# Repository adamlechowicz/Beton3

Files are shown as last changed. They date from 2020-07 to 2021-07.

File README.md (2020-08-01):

# Béton3
**A programmable, QMK-compatible, 3 key macro pad with an OLED screen and concrete knob rotary encoder.**

Definition of béton brut
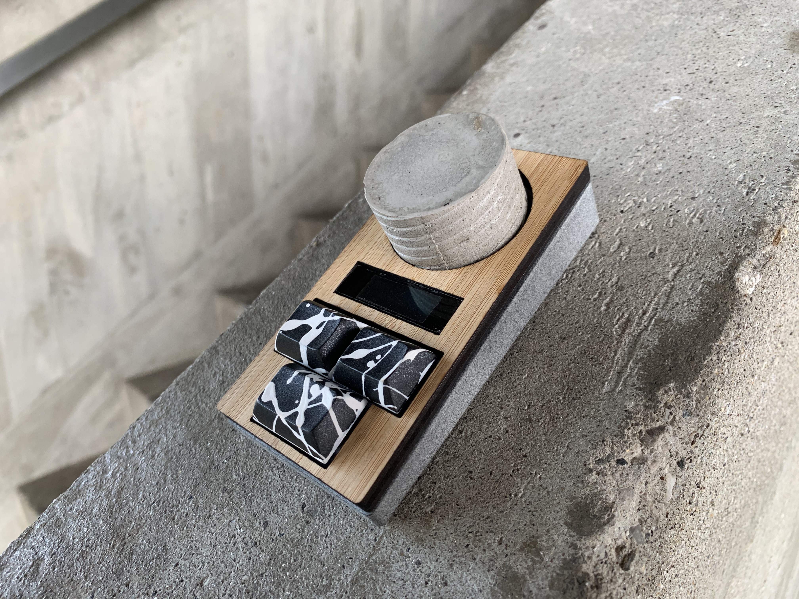
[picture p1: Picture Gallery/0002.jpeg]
Picture of Béton3


Béton3 is an open-source macropad design based around the QMK-compatible Pro Micro platform, MX-mount keyswitches and a commonly available, clickable rotary encoder design.

The defining feature of Béton3 is the cast concrete rotary encoder knob, created using a 3D printed mold that results in a distinct, weighty knob with luxurious inertia and precise steps, much like a premium stereo system.  Using the Béton3 stock firmware, the smooth rotary encoder performs three volume control functions: volume up, volume down, and mute/unmute.

Below the rotary encoder, the 0.91" OLED screen is a bright, programmable canvas for information, text or animations.  Using the Béton3 stock firmware, fluid animations quickly respond to button and knob inputs with icons representing media control and volume control actions.

Finally, three Cherry MX-compatible switches provide a basis for programmable macros, supporting large, 1.25u and 1.5u keycaps for easy muscle memory access.  Using the Béton3 stock firmware, three switches perform five media control functions: play/pause, forward, back, fast-forward, and rewind.

To build your own, consult the [Build Guide.](https://github.com/adamlechowicz/Beton3/tree/master/Build%20Guide)

<a href="https://www.buymeacoffee.com/adamlechowicz" target="_blank">Buy Me A Coffee</a>

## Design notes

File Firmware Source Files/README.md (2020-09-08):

# Béton3 Firmware

This folder holds major versions of the firmware for Béton3.  Firmware is written for Arduino Pro Micro and Pro Micro clones (Arduino Leonardo platform in the Arduino IDE).

I recorded a quick and dirty video of the stock firmware's interface at https://www.youtube.com/watch?v=9jtD4WeTKok

The following open source libraries are dependencies for the firmware:
- [AsyncDelay](https://www.arduinolibraries.info/libraries/async-delay)
- [HID-Project](https://www.arduinolibraries.info/libraries/hid-project)
- [TimerOne](https://www.arduinolibraries.info/libraries/timer-one)
- [U8g2](https://www.arduinolibraries.info/libraries/u8g2)
- [ClickEncoder](https://github.com/0xPIT/encoder)

I've made an attempt to document the majority of the code using comments throughout, but if you are using this as a base for a revision and have clarifying questions shoot me an email at alechowicz@umass.edu.

One thing that may help with code readability as well is the simple wiring diagram hosted in a different folder in this repository, at least in terms of understanding which pins connect to which components.

The stock firmware, without modification, hardcodes a basic media control macro pad, with 3 buttons, a rotary encoder, and animations which correspond to the appropriate button press.
- Button 1: Acts as a play/pause button.  Hold down to open the firmware version screen.
- Button 2: Acts as a media next button.  Hold down to (fast forward only works in Windows).
- Button 3: Acts as a media previous button. Hold down to (rewind only works in Windows).
- Rotary Encoder: Clockwise sends media volume up keystrokes, and counter-clockwise sends media volume down keystrokes.  Click acts as a mute keystroke.  Holding the click opens the "about" screen.

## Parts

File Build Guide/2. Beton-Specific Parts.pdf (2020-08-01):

# Béton3 // Build Guide

# Béton3-Specific Parts

Welcome to the second Build Guide for Béton3. This Build Guide outlines the custom

designed parts you’ll need to build Béton3, along with links to 3D and physical files for each,

and some raw materials you’ll need for final assembly.

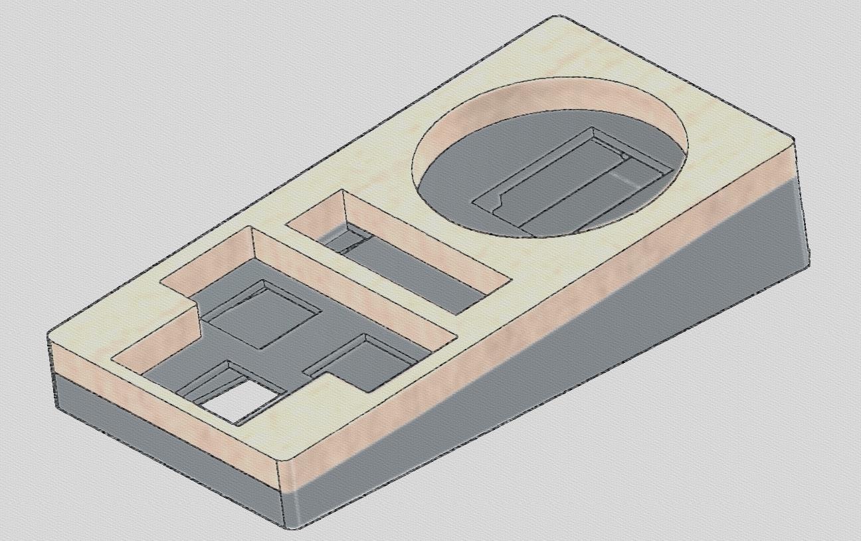
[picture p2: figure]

## Table of Contents

- Pg. 2 – Main Chassis (3D Printed)
- Pg. 3 – Bottom Cover (3D Printed)
- Pg. 4 – Top Bezel (Laser-cut)
- Pg. 5 – Concrete Knob Mold (3D Printed, 3 pieces)
- Pg. 6 – Raw Materials

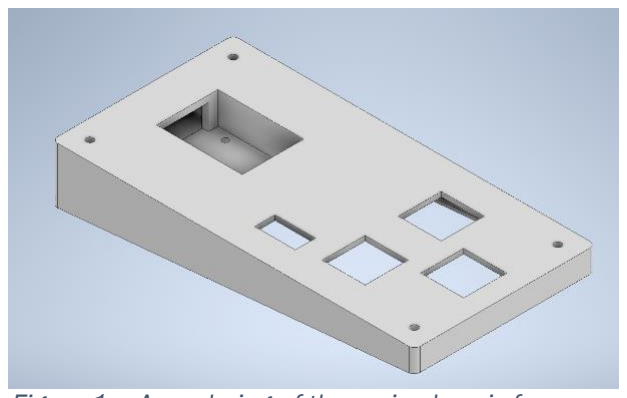
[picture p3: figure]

## Main Chassis (3D Printed)

Béton3’s main chassis is a 3D-printed part. For

best results, I would recommend using a printing

service with a high-resolution printer. I have had

great success with the Multijet Fusion 3D printing

process, available on many sites such as

Shapeways (https://www.shapeways.com/) and Sculpteo. (https://www.sculpteo.com/en/) Notably, for my

rendition of Béton3, I used Multijet Fusion (Not

Dyed, Grey) plastic, which is generally the cheapest option on these printing sites and results

in a unique rough finish that hides layers and blends with the “concrete” aesthetic

reinforced by the encoder knob.

Printing

3D files for the main chassis are available on the Beton3 GitHub repository, with the

filenames betonbase.ipt and betonbase.stl. If you are just printing, you’ll want to download

the STL file as it is compatible with most 3D printing sites (Units are in millimeters).

(Link to files) (https://github.com/adamlechowicz/Beton3/tree/master/Physical%20Files%20(3D%20printing%20and%20laser%20cutting)/3D-printed%20Case)

Figure 1 – A rendering of the main chassis for Béton3

## Bottom Cover (3D Printed)

Béton3’s sliding bottom cover is also a 3D printed

part, which slides along rails shaped into the

main chassis. For best results, I would

recommend using a printing service with a high-

resolution printer. I have had great success with

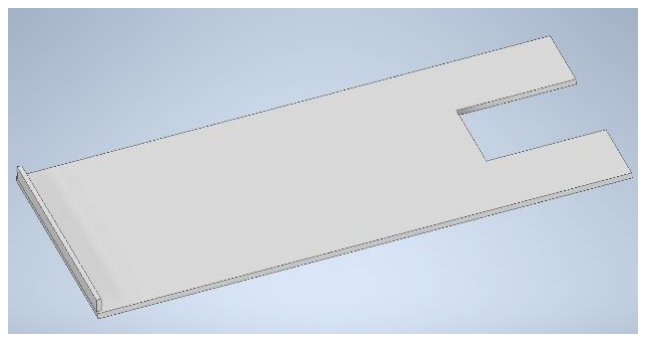
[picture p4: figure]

the Multijet Fusion 3D printing process, available on many sites such as Shapeways (https://www.shapeways.com/) and

Sculpteo. (https://www.sculpteo.com/en/) Notably, for my rendition of Béton3, I used Multijet Fusion (Not Dyed, Grey)

plastic, which is generally the cheapest option on these printing sites and results in a unique

rough finish that hides layers and blends with the “concrete” aesthetic reinforced by the

encoder knob.

You may notice that the bottom cover is not fully rectangular – this is a result of clearance

issues with the frontmost switch. The small cutout allows for plenty of space to solder wires

to that front switch – and don’t worry, it isn’t just left open like that. The gap will be covered

later with a piece of foam, and is completely invisible once assembled.

If you feel strongly about this gap, you could solve this clearance issue by essentially making

the main chassis taller to allow more room – I decided the extra height wasn’t worth it for my

own means.

Printing

3D files for the sliding cover are available on the Beton3 GitHub repository, with the

filenames betonbottom.ipt and betonbottom.stl. If you are just printing, you’ll want to

download the STL file as it is compatible with most 3D printing sites (Units are in

millimeters).

(Link to files) (https://github.com/adamlechowicz/Beton3/tree/master/Physical%20Files%20(3D%20printing%20and%20laser%20cutting)/3D-printed%20Case)

Figure 2 – A rendering of the sliding bottom cover

## Top Bezel (Laser-cut)

Next to the concrete encoder knob,

Béton3’s laser-cut top bezel constitutes

the most distinctive aspect of the design.

The symmetrical layout of the top bezel is

encoded in an Adobe Illustrator file that

can be used with online laser-cutting

services such as Ponoko. (https://www.ponoko.com/)

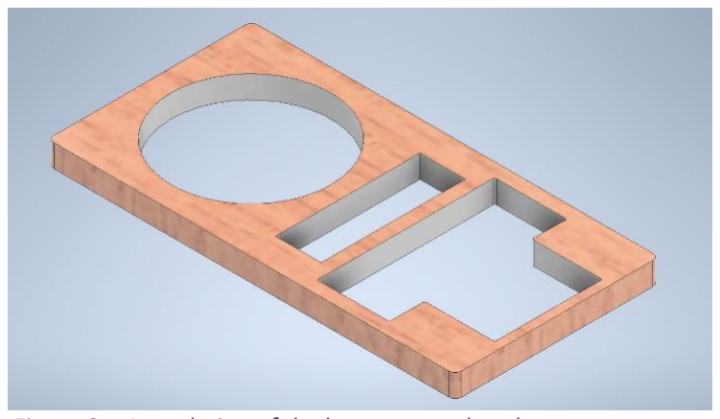
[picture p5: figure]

If you haven’t used an online laser-cutting service, it works much the same way as an online

3D printing service and should be fairly self-explanatory.

Laser Cutting Options

Because the Adobe Illustrator file for this aspect of Béton3 is essentially a 2D file, the top

bezel offers a lot of opportunity for variation and personalization.

For a standard design I would recommend anywhere between 0.24” and 0.26” thickness for

the bezel.

Using Ponoko as an example, there is a wide variety of potential materials to use. You could

use anything from the most basic particleboard to solid walnut hardwood (the price will

reflect your choice, of course). There are also acrylic options, but they may crack using wood

screws, so you might have to devise a different “attachment method”, so to speak. For my

rendition of Béton3, I used Ponoko’s 0.26” thick “Amber Bamboo Plywood” option, which

turned out great. Experiment!

(Link to file) (https://github.com/adamlechowicz/Beton3/tree/master/Physical%20Files%20(3D%20printing%20and%20laser%20cutting)/Laser-cut%20Top%20Bezel)

Figure 3 – A rendering of the laser-cut top bezel.

## Concrete Knob Mold (3D-printed, 3 pieces)

Béton3’s signature feature is a cast,

concrete knob for the rotary encoder.

In order to create the knob, I designed

a specific mold that is 3D printable and

splits into 3 pieces for easy casting,

and features a spiral pattern along the

wall of the knob for grip.

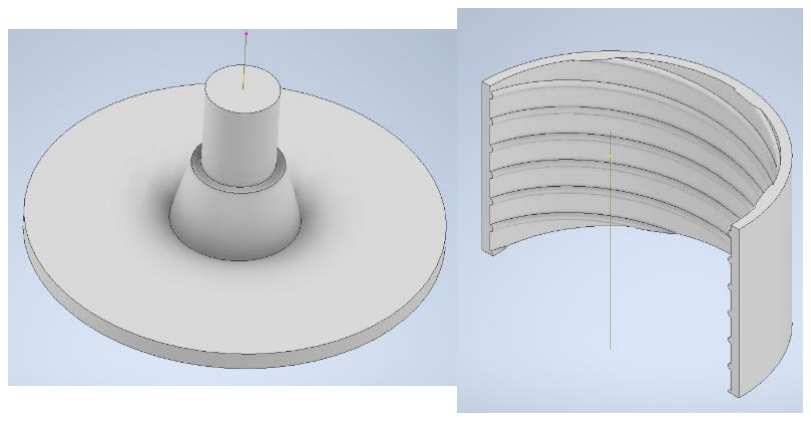
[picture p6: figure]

Like all other 3D printed parts, I would recommend

using a printing service with a high-resolution printer. I have had great success with the

Multijet Fusion 3D printing process, available on many sites such as Shapeways (https://www.shapeways.com/) and

Sculpteo. (https://www.sculpteo.com/en/) For my mold, I used Multijet Fusion (Not Dyed, Grey) plastic, which is generally the

cheapest option on these printing sites.

The actual process of casting the knob is detailed later in the Build Guide, but essentially

two mold sides combine with a mold base to create the full mold.

Printing

3D files for the mold are available on the Beton3 GitHub repository, with the filenames

moldside.ipt, moldside.stl, moldbase.ipt, and moldbase.stl. If you are just printing, you’ll

want to download the STL files as they are compatible with most 3D printing sites (Units are

in millimeters).

You’ll need to print two of the moldside file, and one of the moldbase file.

(Link to files) (https://github.com/adamlechowicz/Beton3/tree/master/Physical%20Files%20(3D%20printing%20and%20laser%20cutting)/3D-printed%20Case)

Figure 4 - The side and base of the concrete mold

## Raw Materials

Finally, you’ll need some basic raw materials to be used for final assembly. These are

commodity items and brand/source isn’t super important, but I have linked some examples

from Amazon that I used/found useful. You may already have some of these materials. Be

sure to check out the later build guides for more information on how I chose all of these, in

case you want to make adjustments:

- Regular Wire – (Amazon) (https://www.amazon.com/gp/product/B07CZT26DM/ref=ppx_yo_dt_b_asin_title_o01_s00?ie=UTF8&psc=1)
- Dupont Wires (with connectors) – (Amazon) (https://www.amazon.com/gp/product/B072L1XMJR/ref=ppx_yo_dt_b_asin_title_o02_s00?ie=UTF8&psc=1)
- Soldering Iron (with solder) – (Amazon) (https://www.amazon.com/gp/product/B07S61WT16/ref=ppx_yo_dt_b_asin_title_o03_s00?ie=UTF8&psc=1)
- Black Matte Plasti Dip (black spray paint should also work) – (Amazon) (https://www.amazon.com/gp/product/B0006SU3QW/ref=ppx_yo_dt_b_asin_title_o04_s00?ie=UTF8&psc=1)
- Electrical Tape, Masking Tape
- 1/16” thick Polycarbonate Sheet – (Amazon) (https://www.amazon.com/gp/product/B07MQTDF4R/ref=ppx_yo_dt_b_asin_title_o06_s00?ie=UTF8&psc=1)
- #2 Wood Screws – ¼” long (you’ll need at least 4)
- Cement (any kind should work, Rockite is a safe and cheap choice) – (Amazon) (https://www.amazon.com/gp/product/B000SDXGUU/ref=ppx_yo_dt_b_asin_title_o07_s00?ie=UTF8&psc=1)
- Hot Glue Gun with Glue Sticks (any temp should work, high temp preferred)
- Sand (any should work as long as doesn’t have too many large rocks or pieces)
- 1/16” thick Neoprene Foam (preferably with adhesive preapplied) – (Amazon) (https://www.amazon.com/6x6-Inch-Neoprene-Plumbing-Material-Protection/dp/B018H9CCPG)

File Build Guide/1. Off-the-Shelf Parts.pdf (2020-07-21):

# Béton3 // Build Guide

# Off-the-Shelf Parts

Welcome to the first Build Guide for Béton3. This Build Guide outlines the “off-the shelf”

parts you’ll need to build Béton3, along with links to purchase compatible parts.


## Table of Contents

- Pg. 2 – Arduino Pro Micro / Pro Micro Clone
- Pg. 3 – Rotary Encoder
- Pg. 4 – 0.91” 128x32 OLED Display
- Pg. 5 – Cherry MX-mount compatible switches
- Pg. 6 – Keycaps

## Arduino Pro Micro / Pro Micro Clone

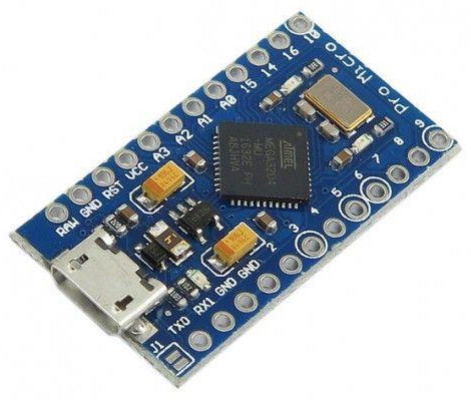
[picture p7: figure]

Béton3 is based on the Arduino Pro Micro platform, a

commonly used platform based on the ATmega32U4

microcontroller. The Pro Micro brings a lot to the table – it’s

affordable, has a vibrant community, and is compatible with

QMK Firmware, (https://docs.qmk.fm/#/) a popular open source firmware for input

devices such as keyboards, mice, and MIDI devices.

Buying Options

One of the best features of the Pro Micro is the sheer spectrum of options available for every

budget.

The most basic option is a Pro Micro clone, the option that I personally chose for my build.

Pro Micro clones are widely available, and generally go for anywhere from $3-10, depending

on shipping speed: (AliExpress) (https://www.aliexpress.com/af/pro-micro.html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) (Amazon) (https://www.amazon.com/s?k=pro+micro&ref=nb_sb_noss_2)

Another option is the SparkFun Pro Micro, the original board design that has since been

cloned endlessly. Theoretically, the SparkFun should perform identically, as it is pin-

compatible with all clones: (SparkFun) (https://www.sparkfun.com/products/12640)

Both above options use micro-USB connectors which have a reputation for breaking off with

lots of insertion cycles. As an alternative, there are some community-made Pro Micro

boards that feature USB-C connectors instead. These boards are more expensive and

higher quality boards that are generally pin-compatible with Pro Micro/clones: (Elite-C V4) (https://keeb.io/products/elite-c-low-profile-version-usb-c-pro-micro-replacement-atmega32u4)

(SparkFun Qwicc) (https://www.sparkfun.com/products/15795)

Figure 1 - A generic Pro Micro clone that you can find everywhere online.

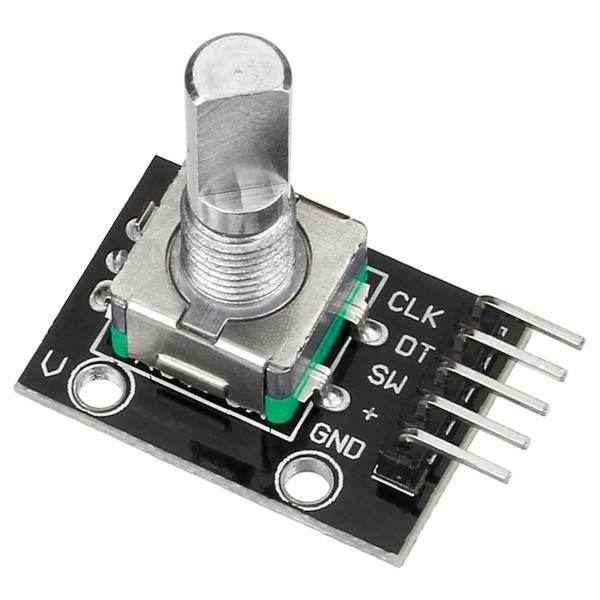
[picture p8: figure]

## Rotary Encoder

Béton3’s chassis is designed around a commonly

available stepped rotary encoder marketed for

Arduino projects. The encoder is sometimes

referred to with a “KY-040” model identifier, and is

generally widely available on e-commerce sites.

Minor differences such as PCB color should be

irrelevant, as long as the PCB form factor is the

same size and the encoder has 5 pins.

Buying Options

These encoders can be picked up for as low as $0.47 on AliExpress. If Prime shipping is

more your speed, you can pick up a pack of multiple encoders for about $1 per encoder:

(AliExpress) (https://www.aliexpress.com/af/rotary-encoder-ky%25252d040.html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)

(Amazon) (https://www.amazon.com/s?k=rotary+encoder+ky-040&ref=nb_sb_noss_1)

Figure 2 - An example of the rotary encoder in question.

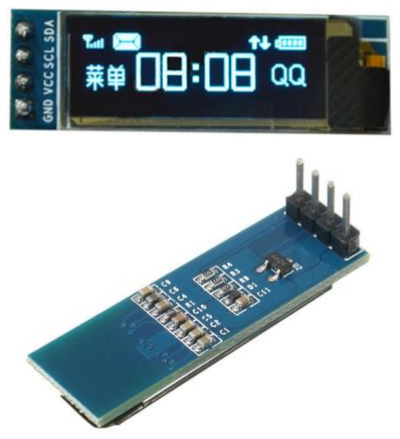
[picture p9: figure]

## 0.91” 128x32 OLED Display

Béton3’s chassis is designed around a particularly

affordable 0.91” OLED screen with 128x32 pixels

that has been used in a few keyboards, most notably

the Satisfaction 75. (https://cannonkeys.com/collections/satisfaction-75)

Like the other parts on this list, this display is

generally widely available on e-commerce sites.

Minor differences such as PCB color are irrelevant,

but watch out for cheaper SKUs of the display on

AliExpress which do not include the PCB.

Buying Options

There are two primary variants of this display, a monochrome blue variant, and a

monochrome white variant. I chose the monochrome white display, but this distinction is up

to personal preference.

These little screens can be picked up for as low as $1.10 on AliExpress. If Prime shipping is

more your speed, you can pick up a screen on Amazon for about $7-8; less if you buy

multiple in a pack.

(AliExpress) (https://www.aliexpress.com/af/128x32-oled.html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)

(Amazon) (https://www.amazon.com/s?k=128x32+oled&ref=nb_sb_noss_2)

Figure 3 – An example of the 128x32 OLED display with the PCB.

## Cherry MX-mount compatible switches


Béton3’s chassis includes 3 square mounting holes

compatible with Cherry MX switches and MX-

compatible switches (Gateron, Kalih BOX, Zeal,

Outemu, etc.) For my initial build, I used an

assortment of Gateron Linears I had sitting in a

drawer, but you’ll probably use your preferred switch.

Switches can cost anywhere from pennies per switch

up to $1 per switch or more for some enthusiast

switches like Zealios or Holy Pandas.

Buying Options

Switches can be found on an endless number of websites all over the internet. There is a

great switch guide (https://www.reddit.com/r/MechanicalKeyboards/wiki/switch_guides) on /r/MechanicalKeyboards that outlines what types of switches are

available and some direction on where to buy them. As usual, some of the more common

switch types manufactured in China are available on AliExpress (https://www.aliexpress.com/af/keyboard-switch.html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) in packs for fairly affordable

prices.

I strongly recommend checking out any one of the multiple mechanical keyboard

communities online for more info about keyswitches.

Figure 4 - The three mounting holes for MX-compatible switches on the Béton3 chassis

## Keycaps

For the three macro keys, Béton3 uses a

somewhat non-standard layout for keycaps.

Keycaps naturally must be MX-compatible cross-

stem keycaps. The layout is comprised of two

upper 1.25u keycaps, and one lower 1.5u keycap.

If you are unfamiliar with keycap sizing in terms of

“u”s, this is an example of a standard keyboard

layout with labeled sizes. (https://support.wasdkeyboards.com/hc/en-us/articles/115009701328-Keycap-Size-Compatibility)


For a standard ANSI keyboard layout, 1.5u is equivalent to the “Tab” key, and 1.25u is

generally equivalent to one of the modifier keys (Ctrl, Alt, Command).

Buying Options

While basic 1u (square-shaped) keycaps are commonplace and can be purchased in small

batches or one-by-one, 1.25u and 1.5u keycaps are a bit more difficult to find.

For a basic option, there is a basic set of 1.25u and 1.5u DSA PBT keycaps available on

AliExpress (https://www.aliexpress.com/af/1.5u-keycap.html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) for about $7.

For something more interesting, you may be able to find “artisan” keycaps on sites such as

Etsy or eBay in the 1.25u and 1.5u sizes.

Finally, if you have spare keycaps lying around the house, you may be able to use keycaps

from your existing set such as “Tab”, “Ctrl”, “Alt”, “|\”, etc.

Please note: Although aesthetically awkward, standard 1u keycaps will fit, and are

completely functional despite the gaps.

Figure 5 - Keycap size layout

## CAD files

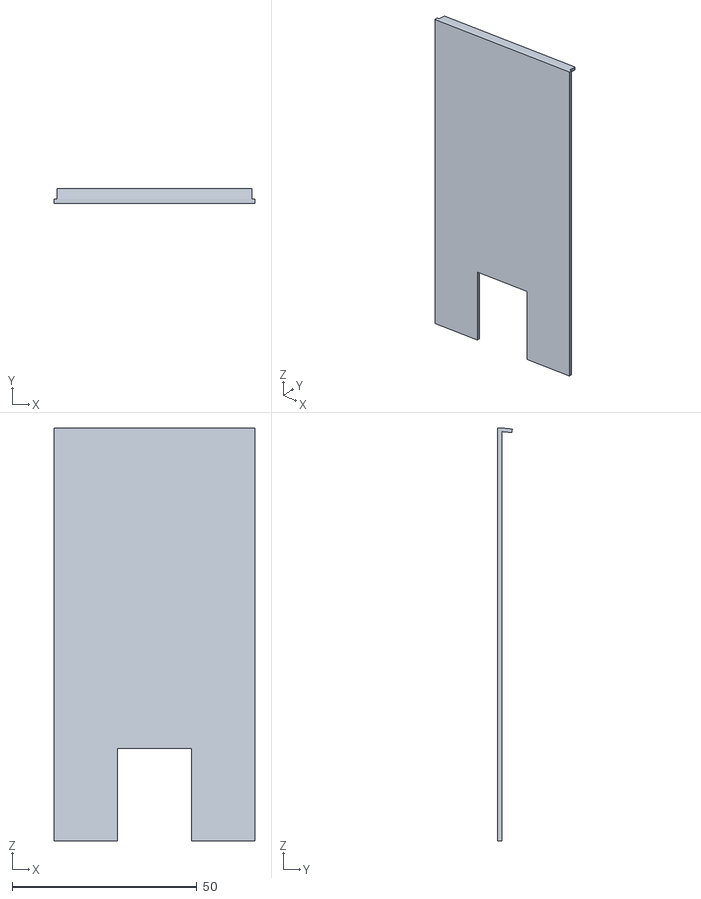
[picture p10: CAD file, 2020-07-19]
Physical Files (3D printing and laser cutting)/3D-printed Case/betonbottom.stl
54.4 x 3.98 x 111.8

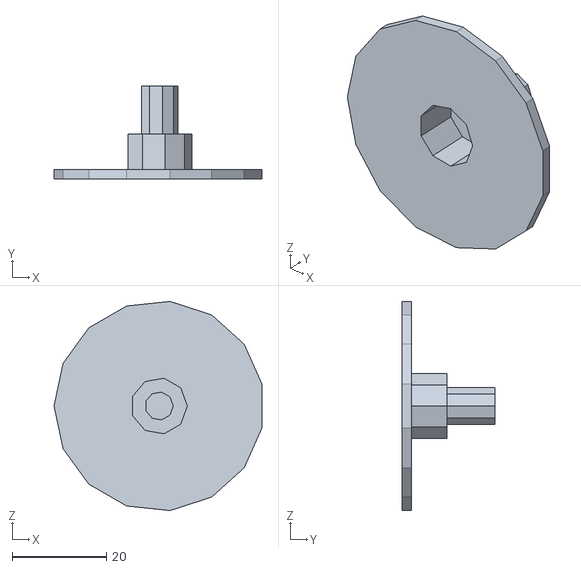
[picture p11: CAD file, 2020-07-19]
Physical Files (3D printing and laser cutting)/3D-printed Concrete Mold/moldbase.stl
44.2 x 19.8 x 44.5

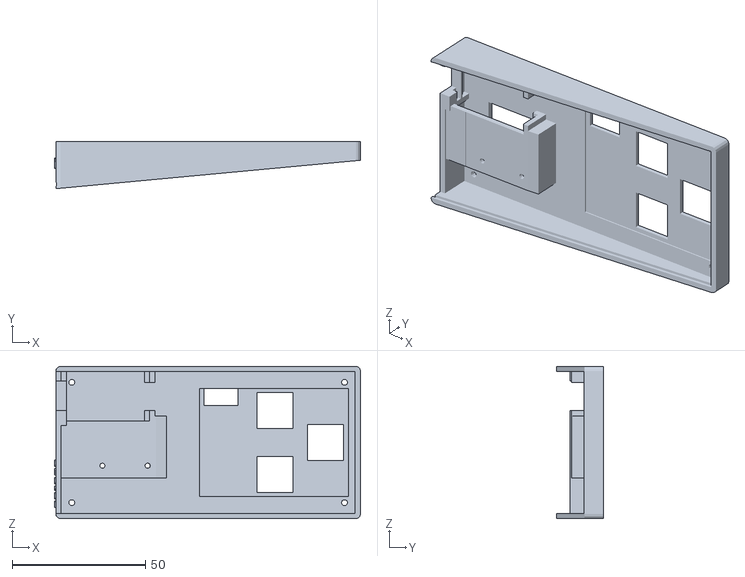
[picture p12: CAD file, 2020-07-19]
Physical Files (3D printing and laser cutting)/3D-printed Case/betonbase.stl
114.8 x 17.8 x 57.2

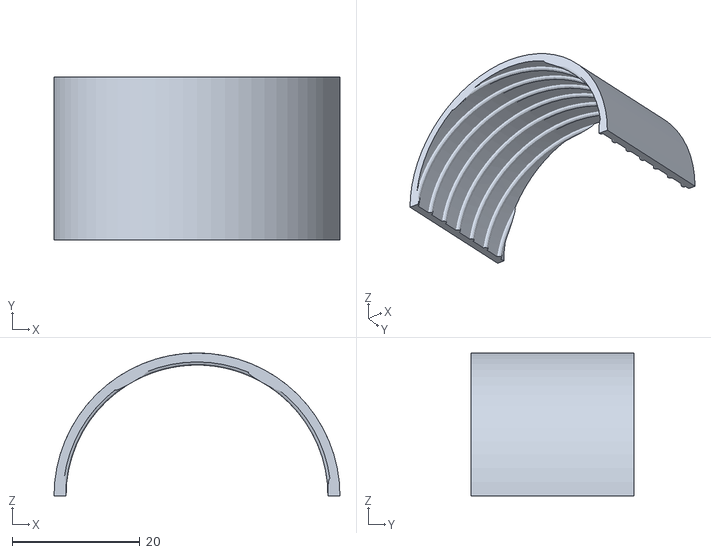
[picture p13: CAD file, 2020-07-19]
Physical Files (3D printing and laser cutting)/3D-printed Concrete Mold/moldside.stl
44.7 x 25.4 x 22.4

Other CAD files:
Physical Files (3D printing and laser cutting)/3D-printed Case/betonbase.ipt
Physical Files (3D printing and laser cutting)/3D-printed Case/betonbottom.ipt
Physical Files (3D printing and laser cutting)/3D-printed Concrete Mold/moldbase.ipt
Physical Files (3D printing and laser cutting)/3D-printed Concrete Mold/moldside.ipt
Physical Files (3D printing and laser cutting)/Full Assembly (Autodesk Inventor)/Assembly Beton (shrinkwrapped).ipt

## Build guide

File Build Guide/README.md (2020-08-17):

# Béton3
# Build Guide

The Build Guide for Béton3 is split up into topics, with PDF files for each topic:

**note:** Links don't seem to work through the GitHub PDF viewer.  Download the PDF files if necessary.

1. **Off-the-Shelf Parts**
2. **Beton-Specific Parts**
3. **Soldering Guide**
4. **Final Assembly Guide**

- Appendix A. **Making a Screen Bezel from Polycarbonate**
- Appendix B. **Casting a Concrete Volume Knob**
- Appendix C. **Flashing Beton3 Stock Firmware**

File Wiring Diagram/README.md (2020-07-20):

# Béton3
# Wiring Diagram

Files:
- **Wiring Diagram.pdf** - A pretty basic PDF outline of the wiring for Béton3.

This wiring diagram is intended as a quick reference guide to the wiring setup I used for Béton3.  This diagram should work verbatim for all Arduino Pro Micros, Pro Micro clones, and Pro Micro pin-compatible boards.  Boards that are a similar form factor but not pin-compatible may require some shuffling around on your end.

- **Rotary Encoder**
  - GND to GND on Pro Micro
  - **+** to RAW (6-12V) on Pro Micro
  - SW to A2 on Pro Micro
  - DT to A1 on Pro Micro
  - CLK to A0 on Pro Micro

- **OLED Display**
  - GND to GND on Pro Micro
  - VCC to VCC on Pro Micro
  - SDA to SDA (pin 2) on Pro Micro
  - SCL/SCK to SCL (pin 3) on Pro Micro
  
- **Switch #1**
  - One pin to GND on Pro Micro
  - Other pin to PIN 7 on Pro Micro
  
- **Switch #2**
  - One pin to GND on Pro Micro
  - Other pin to PIN 8 on Pro Micro

- **Switch #3**
  - One pin to GND on Pro Micro
  - Other pin to PIN 9 on Pro Micro

For more information on wiring up Béton3, consult the [Build Guide.](https://github.com/adamlechowicz/Beton3/tree/master/Build%20Guide)

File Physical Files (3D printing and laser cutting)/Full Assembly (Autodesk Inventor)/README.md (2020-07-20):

# Béton3
# Assembly Example

Files:
- **Assembly Beton (shrinkwrapped).ipt** - An Autodesk Inventor part file that is a simple representation of how Béton3 assembles.  3D files incorporated are included elsewhere in the repository.

For more information on the assembling Béton3 parts, consult the [Build Guide.](https://github.com/adamlechowicz/Beton3/tree/master/Build%20Guide)

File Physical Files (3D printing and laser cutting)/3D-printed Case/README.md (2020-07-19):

# Béton3
# 3D-printed Case

Files:

- betonbase.ipt - Original Autodesk Inventor file
- **betonbase.stl** - The primary structural base for Béton3.  STL File uses millimeters for units.

- betonbottom.ipt - Original Autodesk Inventor file
- **betonbottom.stl** - Bottom sliding cover for Béton3.  STL File uses millimeters for units.

The STL files can be directly uploaded to a 3D-printing service for printing.  In my initial build, I used [Sculpteo](https://www.sculpteo.com/en/) for printing, and chose Multijet Fusion (Not Dyed, Grey) plastic.  Not only is this plastic the cheapest option on many 3D-printing sites, the Multijet Fusion process creates a unique rough finish that hides layers and blends with the "concrete" aesthetic of Béton3, while striking a great balance between elasticity and rigidity.

As I don't personally have one, I have not tried printing these files with a desktop printer such as a MakerBot.  Some part geometry may have to be modified for a satisfactory result on a "traditional" FDM printer.

For more information on the 3D-printed main case, consult the [Build Guide.](https://github.com/adamlechowicz/Beton3/tree/master/Build%20Guide)

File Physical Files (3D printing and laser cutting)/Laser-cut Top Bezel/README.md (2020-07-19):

# Béton3
# Laser-cut Top Bezel

Files:
- **topbezel.ai** - An Adobe Illustrator file to use with a laser cutting service such as [Ponoko](https://www.ponoko.com/), in order to create the top bezel for Béton3.

This file can be directly uploaded to Ponoko for laser-cutting.  For best results, the thickness of the top bezel should be between 0.24 and 0.26 inches.

For the material, anything wood or wood-adjacent (plywood, particleboard) should work, as long as you can use screws to attach the top bezel to the 3D-printed case.  I have not tested other types of materials such as acrylic, although they should theoretically work, assuming you can attach the resulting product to the bottom case.

For more information on the top bezel, consult the [Build Guide.](https://github.com/adamlechowicz/Beton3/tree/master/Build%20Guide)

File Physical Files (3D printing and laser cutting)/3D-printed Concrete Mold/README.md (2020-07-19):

# Béton3
# 3D-printed Concrete Knob Mold

The 3D files in this folder combine to create a concrete mold for Béton3's rotary encoder knob.

Files:

- moldside.ipt - Original Autodesk Inventor file
- **moldside.stl** - 180 degrees of the concrete mold's side.

- moldbase.ipt - Original Autodesk Inventor file
- **moldside.stl** - Concrete mold's base.

In order to create a functioning mold, you'll need to print 2 of the moldside file, and 1 of the moldbase file.

For more information on using the resultant mold, consult the [Build Guide.](https://github.com/adamlechowicz/Beton3/tree/master/Build%20Guide)

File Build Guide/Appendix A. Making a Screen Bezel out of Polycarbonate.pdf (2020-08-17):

# Béton3 // Build Guide

# Appendix A: Making a Screen Bezel from Polycarbonate

Welcome to Appendix A: Making a Screen Bezel from Polycarbonate. This quick guide will

guide you through the process making a polycarbonate screen bezel out of a sheet of

commodity 1/16” inch thick clear polycarbonate.


## Table of Contents

- Pg. 2 – Overview of Materials
- Pg. 3 – Cutting the Polycarbonate to Size
- Pg. 4 – Masking Off the Polycarbonate
- Pg. 5 – Painting the Polycarbonate

## Overview of Materials

In order to create a polycarbonate screen bezel, you’ll need the following materials and

parts:

1. A sheet of clear polycarbonate, 1/16” inch thick.
2. Utility knife
3. Fine-tip marker or sharpie
4. Ruler/Straight Edge
5. Black Plasti Dip or Spray Paint (personal preference)
6. Masking tape or electrical tape
7. Scissors
8. (recommended) Beton3 Wooden Top Bezel (to test fit)
9. Sandpaper (to make minor adjustments if cut too big)

## Cutting the Polycarbonate to Size

First, you’ll want to cut a rectangle out of the polycarbonate sheet.

The size of the screen bezel will be 39.5 mm x 11.5 mm.

I found that the best way to do this is using the “score and snap” method outlined under

“Method 1” on wikiHow: https://www.wikihow.com/Cut-Polycarbonate

Use the ruler to mark off the rectangle you’re trying to cut on the protective white plastic

that’s covering the polycarbonate underneath. Follow the wikiHow guide to score the

polycarbonate, and snap it off, leaving a clean, straight edge.

I would recommend starting with the long side first, wasting less polycarbonate in case you

decide to retry, like so:

If you have a laser-cut top bezel, try test fitting the rectangle into the cutout for the OLED

display to see if it will fit. Use sandpaper to sand off some polycarbonate if it “almost” fits in

the rectangular cutout.

Once you’ve scored and snapped a satisfactory rectangle of polycarbonate, peel off the

white protective plastic on ONE side and proceed to the next step.

39.5 mm

11.5 mm

Polycarbonate Sheet

B
E
Z
E
L

## Masking Off the Polycarbonate

Once you’ve cut out this rectangle, the final step is to paint the excess polycarbonate around

the edges of the OLED display. In order to do this, the first step will be to mask off a

rectangular cutout of the polycarbonate rectangle where the OLED display will shine through.

Use scissors to cut out a rectangle of masking tape or electrical tape and position it as such:

The tape should be

25 mm x 8 mm.

When positioning the tape, be cognizant of the display’s position relative to the rectangular

cutout in the wooden laser-cut bezel. For me, this was roughly centered, but this may be

different for you, especially if you’ve already substantially completed a Beton3.

You’ll want to stick this tape to the side of the polycarbonate rectangle where you have

peeled off the white protective plastic.

The other side of the bezel should still have white protective plastic covering it, to prevent

any paint from getting on that side. If your polycarbonate sheet didn’t come with a white

protective sheet on both sides, take a large piece of masking tape or electrical tape and

mask off the entire other side of the polycarbonate sheet too – this will be critical to the final

look.

Once finished masking, go on to painting!

Polycarbonate

Rectangle

Masking Tape or Electrical Tape

25 mm

8 mm

## Painting the Polycarbonate

Once you’ve masked everything off, set the polycarbonate down somewhere where you can

use spray paint, with the 25 x 8 mm cut rectangle of tape facing UP. Now, using either your

black Plasti Dip or black spray paint, spray the polycarbonate from all four sides, at about a

45º angle from the ground. This will evenly coat both the back of the bezel, and the sides,

hiding any imperfections in the scored sides of the bezel.

Don’t use too much – you want to be able to peel off that tape, and one good coat is more

than sufficient.

Leave the bezel somewhere to dry for a little bit.

After roughly 30-45 minutes (depending on the paint you used), go back and peel off the

masking or electrical tape that you used earlier. Doing this step before the pain cures

completely gives a cleaner line. If you are having trouble getting the tape free of the rest of

the paint, you can lightly try using a razor blade or an X-Acto knife to cut around the edge of

the tape and peel it away.

Once all the masking tape is gone, you have successfully made a polycarbonate OLED

screen bezel out of a sheet of polycarbonate!

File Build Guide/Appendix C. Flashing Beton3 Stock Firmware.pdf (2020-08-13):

# Béton3 // Build Guide

# Appendix C: Flashing Beton3 Stock Firmware

Welcome to Appendix C: Flashing Beton3 Stock Firmware. This quick guide will guide you

through the process of flashing a Pro Micro/Pro Micro compatible board with the Beton3

Stock Firmware, which is recommended to be completed after final assembly is complete.


## Table of Contents

- Pg. 2 – What You Will Need
- Pg. 3 – Setting Up Environment (Arduino IDE and required libraries)
- Pg. 4 – Downloading and Opening Stock Firmware
- Pg. 5 – Final Steps, Flashing and Testing

## What You Will Need

Before flashing the stock firmware, you’ll need access to the following:

1. A computer that can run Arduino IDE (Windows, Mac and Linux are a safe bet)
2. A compatible USB Cable that can connect from your Pro Micro to said computer

(probably microUSB or USB-C)

3. An assembled Beton3 (note: you can theoretically flash the Pro Micro by itself, but

testing is pretty much impossible without components connected)

4. Internet connection

## Setting Up Environment (Arduino IDE and required libraries)

Step 1. Install Arduino IDE:
- Download and Install (https://www.arduino.cc/en/main/software)
- Use the guide (https://www.arduino.cc/en/Guide) if necessary
Step 2. Download Required Libraries (.zip files, get the latest version):
- AsyncDelay (https://www.arduinolibraries.info/libraries/async-delay)
- HID-Project (https://www.arduinolibraries.info/libraries/hid-project)
- TimerOne (https://www.arduinolibraries.info/libraries/timer-one)
- U8g2 (https://www.arduinolibraries.info/libraries/u8g2)
- ClickEncoder (https://github.com/0xPIT/encoder)

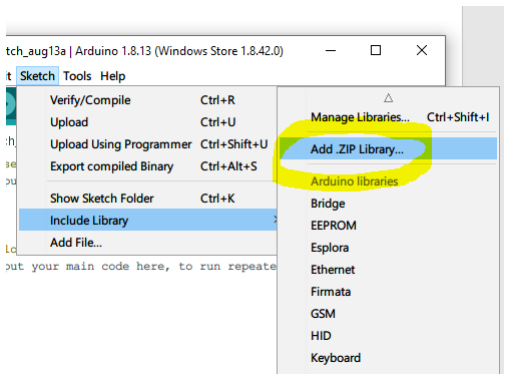
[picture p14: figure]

Step 3. Install Required Libraries
- In Arduino IDE, go to Sketch > Include

Library > Add .ZIP Library… and click

- Choose one of the five .zip files you

downloaded in Step 2 and click “Open”

- Repeat for the other four .zip files you

downloaded in Step 2

Step 4. Configure Arduino Mode
- In Arduino IDE, go to Tools > Board: “…” > and click “Arduino Leonardo”.

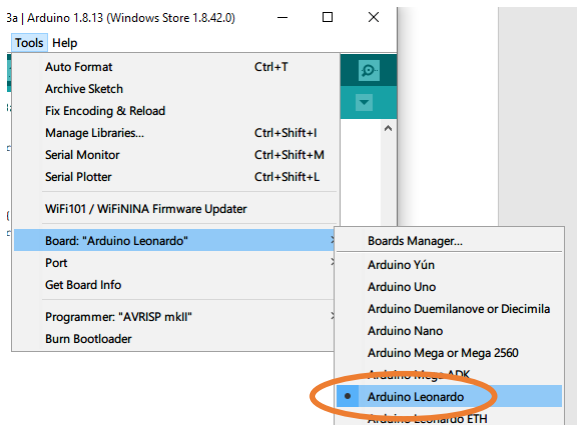
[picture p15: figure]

## Downloading and Opening Stock Firmware

Step 1. Cloning the Repository
- If you haven’t already, clone the entire repository (https://github.com/adamlechowicz/Beton3) to your computer. If you’re familiar

with Git, do this step however you see fit, but if you aren’t, continue…

- On GitHub, hover over “Code” and click

“Download ZIP”.

- Save the repository somewhere

convenient

Step 2. Opening the Firmware in Arduino IDE
- Navigate to the repository folder and into

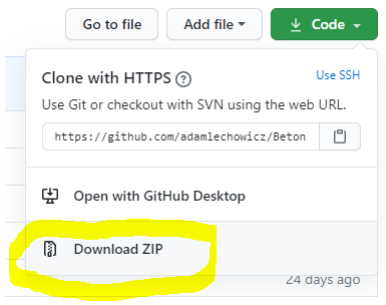
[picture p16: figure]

the “Firmware Source Files” folder within, then into “beton_firmwareX.X”, then into

“beton”.

- Within that folder, you’ll see

the following directory

structure:

- Double click on the

beton.ino file.

- Once the file opens, you

should see all of the

firmware files automatically

open in Arduino IDE (beton,

acknowledge.h,

forwardback.h, nextprev.h,

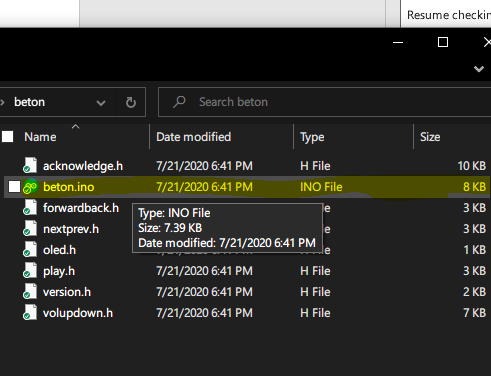
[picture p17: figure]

oled.h, play.h, version.h, volupdown.h)

## Final Steps – Flashing and Testing

Step 1. Flash!
- Now that the project is open in Arduino IDE, connect your Beton3 using your USB

cable. The Pro Micro should automatically be detected by Arduino IDE.

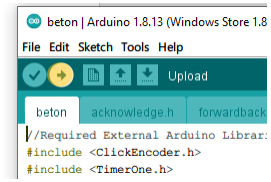
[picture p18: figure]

- Click the upload button (highlighted in

yellow to the right) to flash the firmware.

Step 2. Test!
- Once complete, test out Beton3 by keeping it connected to your computer. As soon

as the flash is completed, the OLED screen should display a quick splash screen

reading “Beton3”.

- As soon as the splash screen goes away, the rotary encoder should be functioning as

a volume knob.

- Button 1 should function as a play/pause button.
- Button 2 should function as a back/rewind button.
- Button 3 should function as a forward/fast-forward button.
- Finally, clicking on the rotary encoder should function as a mute toggle.
- Upon inputs, the OLED screen should display animations.

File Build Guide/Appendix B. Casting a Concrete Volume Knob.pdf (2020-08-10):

# Béton3 // Build Guide

# Appendix B: Casting a Concrete Knob

Welcome to Appendix B: Casting a Concrete Knob. This quick guide will guide you through

the process of casting a concrete knob using cement, sand, water, and the three 3D-printed

mold components.


## Table of Contents

- Pg. 2 – Overview of Materials
- Pg. 3 – Prep Work for the Mold & Video Example
- Pg. 4 – Pouring Concrete
- Pg. 5 – Extracting from the Mold

## Overview of Materials

Before casting a concrete knob, you’ll need the following materials and parts:

1. Cement
2. Sand
3. Water
4. Vaseline (Petroleum Jelly)
5. Sturdy Tape (Gorilla Tape, Duct Tape, or Electrical Tape)
6. 2x 3D-Printed Mold Side
7. 1x 3D-Printed Mold Bottom
8. A cup or bowl for mixing concrete
9. A spoon to mix and scoop concrete.

## Prep Work for the Mold & Video Example

First, you’ll want to assemble the 3-part

mold.

The mold is fairly self-explanatory to put

together. The two sides are the most

difficult part – the spiral embossing on

the side wall only aligns one way.

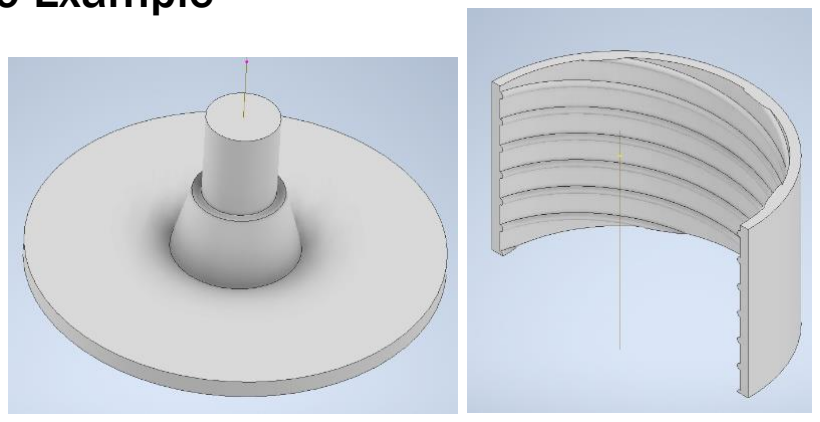
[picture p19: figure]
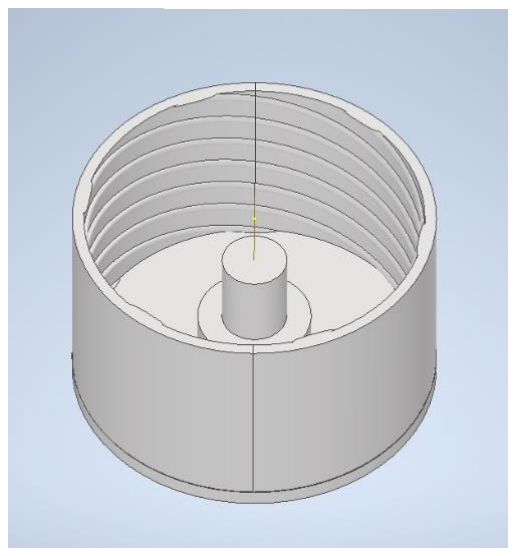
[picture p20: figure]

Use tape to tape the sides together to create a circular ring.

The final step entails taping the ring down on top of the

bottom mold part, to create the full mold cavity. You’ll want

to tape the ring around the full way around, making a 360

degree seal along the bottom edge of the mold.

Finally, use some petroleum jelly (Vaseline) to lightly coat all

of the inner surfaces of the mold. This step will make it

much easier to separate the mold pieces from the concrete

itself.

Mixing Cement

In order to create the concrete mix, you’ll want to mix 1 part cement and 1 part sand in a

small cup. Two tablespoons of each should be plenty. Easily the most difficult part of this

process is the amount of water to add to the sand-cement mix – depending on the type of

cement you have, this amount may differ.

I would highly recommend adding a drop of water at a time to get the mix just right.

This video by DIY Perks, (https://youtu.be/sJ5vhShdVjo?t=490) while a very different process, is the basis that I used for my

concrete mix consistency.

Figure 3 An example of what the completed mold will look like

Figure 1 The bottom part of the mold Figure 2 One of two sides of the mold

## Pouring Concrete

Once you have your concrete mix ready, it’s time to cast the knob itself.

Like the previous step, I recommend watching this video by DIY Perks (https://youtu.be/sJ5vhShdVjo?t=490) to get a feel for the

actual pouring.

I would recommend using a spoon to slowly fill in the mold, bit by bit, tapping the side of the

mold intermittently to level out the mixture.

Once the mold is full, you can do several finishing steps – if you just want a smooth, even

top surface, tap the mold a few times to level everything out.

You can also take a small dollup of leftover concrete mix and drop it anywhere on the top of

the drying concrete, without tapping the mold, to create a grippy, natural looking nub on the

resultant knob.

Depending on the cement you used, the cure time will be different, but it should be cured

within a general window of 1-4 hours.

## Extracting from the Mold

Once the knob is cured, the last step is to extract the knob from the mold.

First, without applying much pressure on the concrete itself, peel all the tape off that is

holding the three pieces of the mold together.

You’ll want to start with the mold sides. Use the lip at the top edge of each side piece to

lightly peel one side at a time – these pieces should come off without too much effort.

Finally, the bottom piece – depending on the quality of your 3D-printed mold piece, this

piece may be affixed somewhat tightly to the knob, but it can be pried off. Assuming that

the bottom piece doesn’t simply fall off, a safe bet is to start with a knife, guitar pick, or

credit card to wedge in between the concrete knob itself and the actual bottom mold piece,

to get a little bit of leverage and create a small gap.

Once you have a small gap between the concrete and the bottom plate, you’ll want to grab

the concrete knob in one hand and use your other hand to rock the remaining mold piece

back and forth, pulling outwards.

Eventually, the bottom piece will pop out with enough leverage and enough rocking.

Congratulations! You have cast a concrete rotary encoder knob!

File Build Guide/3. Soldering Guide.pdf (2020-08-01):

# Béton3 // Build Guide

# Soldering Guide

Welcome to the third Build Guide for Béton3. This Build Guide outlines a basic overview of

the soldering and wiring you’ll need to do in order to assemble Béton3.


## Table of Contents

- Pg. 2 – Overview
- Pg. 3 – Dupont Wire Modification
- Pg. 4 – Rotary Encoder Wires
- Pg. 5 – OLED Display Wires
- Pg. 6 – Switch Wiring
- Pg. 7 – Wiring Diagram (reference)

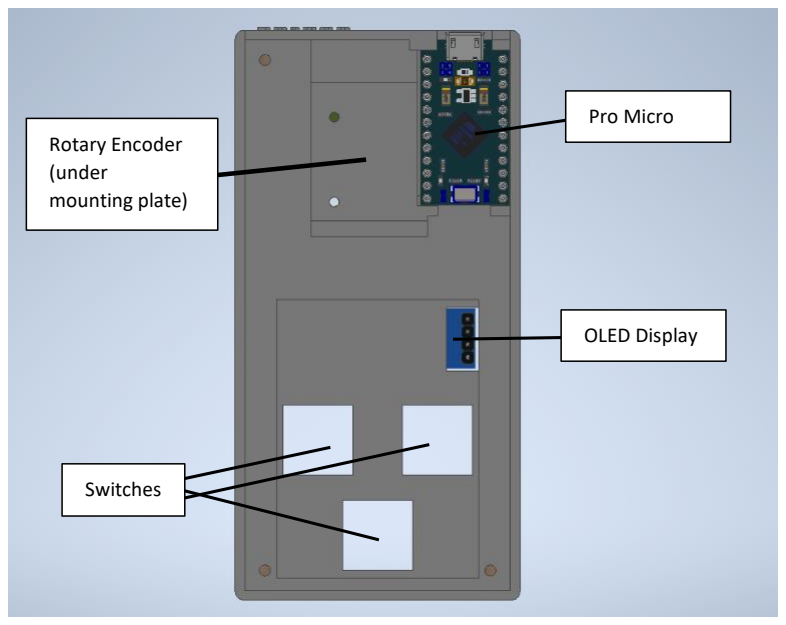
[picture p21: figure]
Rotary Encoder (under mounting plate); Pro Micro; OLED Display; Switches

## Overview

Before starting with soldering assembly,

gather some supplies:

- Dupont Wire
- Regular Wire
- Soldering Iron
- Electrical Tape
- Wire Cutters

Layout

Looking at the chassis from underneath, the Pro Micro gets nestled in the top right, the

rotary encoder gets inserted from the other side into a mounting “bracket” designed into the

case, with its pins facing towards the back of the unit. The OLED display will get mounted to

the top of the chassis, with its pins poking through the small hole for wiring. Finally, the

switches are mounted in regular fashion into their respective mounting holes and wired

accordingly.

Keep this layout in mind when you solder wires to the Pro Micro. I would highly recommend

having the chassis part physically near you while you solder, so that you can essentially

perform “test fits” after completing a few wires and see whether or not the length is good.

Figure 1 – The layout of components underneath

## Dupont Wire Modification

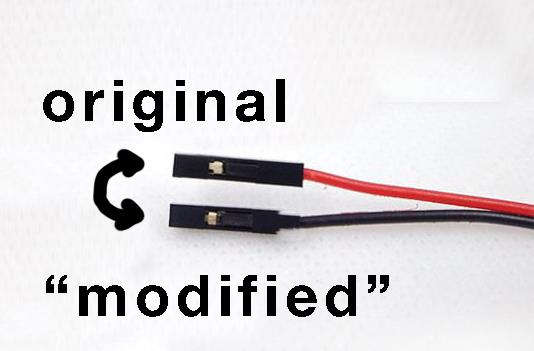
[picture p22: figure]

Building Béton3, I used Dupont wires to

connect the Pro Micro to components

that have existing pins soldered on

(rotary encoder, OLED display).

This step is theoretically optional,

depending on how comfortable you are

with desoldering pins or using an

alternate method of attachment.

The commonly available type of Dupont

wires have the connector seen in the

figure to the right. A small modification is required to make them fit in the chassis’ tight

fitting case – using a small wire cutter, you’ll want to trim the black plastic from around the

wire at the wire-facing end. This modification doesn’t affect functionality and gives the wire

a bit more flexibility to bend and conform to tight spaces.

You’ll want to do this modification to any Dupont wires used throughout this guide.

Figure 2 - An example of the modification required for the Dupont wires.

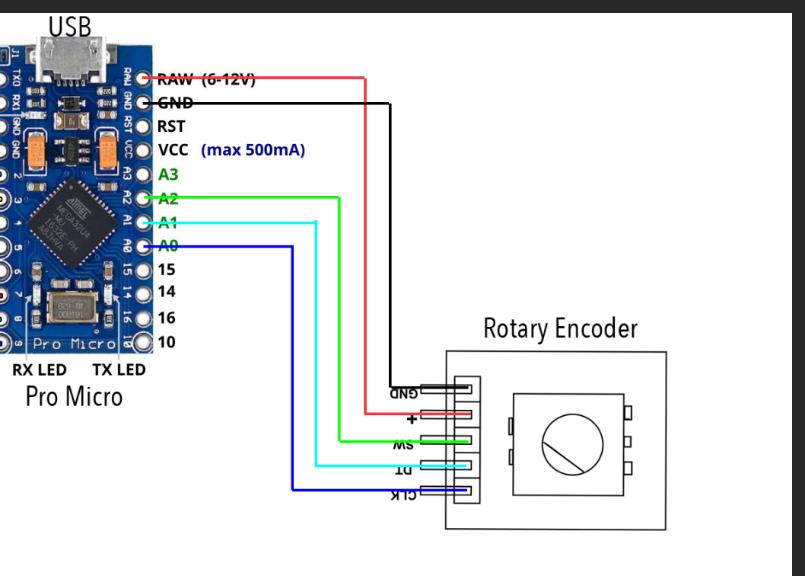
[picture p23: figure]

## Rotary Encoder Wires

Gather the following:

- 5 Dupont Wires (female end)

Wiring description:

- Pin RAW on Pro Micro → + on Rotary Encoder
- Pin GND on Pro Micro → GND on Rotary Encoder
- Pin A2 on Pro Micro → SW on Rotary Encoder
- Pin A1 on Pro Micro → DT on Rotary Encoder
- Pin A0 on Pro Micro → CLK on Rotary Encoder

Procedure

Starting with the Rotary Encoder wiring, you’ll want to get 5 Dupont wires with female ends

(these ends will connect to the rotary encoder) and cut them to size. You’ll notice that the

rotary encoder and Pro Micro are tightly packed next to each other in the chassis, so you’ll

want to cut the wires to be long enough to thread through to the other side and connect to

the rotary encoder, but also short enough to fit in that small space in between the two.

In final assembly, the excess of these wires should tuck neatly in the space underneath the

Pro Micro (looking at it from the bottom).

Figure 3 – A simple line representation of the wiring for the Rotary Encoder

## OLED Display Wires

Gather the following:

- 4 Dupont Wires (female end)

Wiring description:

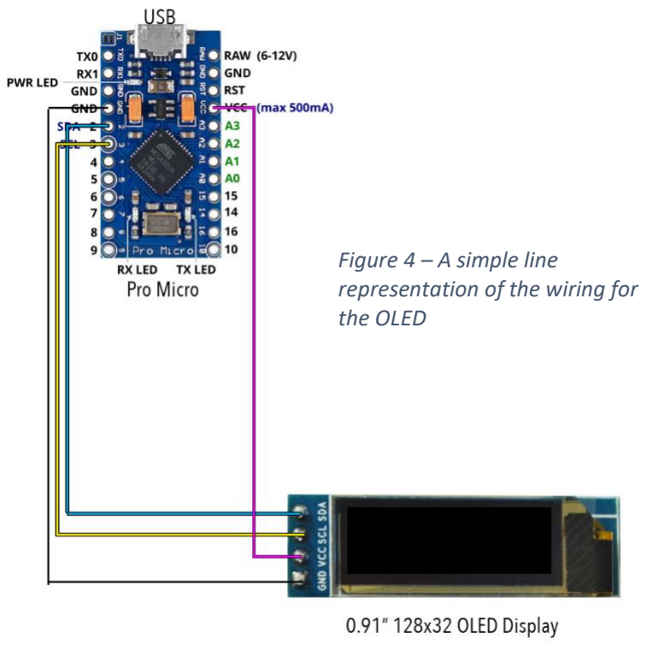
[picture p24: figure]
Figure 4 – A simple line representation of the wiring for the OLED

- Pin VCC on Pro Micro → VCC on OLED
- Pin GND on Pro Micro → GND on OLED
- Pin SDA (pin 2) on Pro Micro → SDA on OLED
- Pin SCL (pin 3) on Pro Micro → SCL/SCK on Rotary Encoder

Procedure

For the OLED wiring, you’ll want to get 4 Dupont wires with female ends (these ends will

connect to the rotary encoder) and cut them to size. You’ll want to cut the wires to be long

enough to reach the OLED pins poking through the chassis underneath the Pro Micro, but

short enough to avoid bunching up and taking up space that will be needed for switch

wiring.

Make sure you check that the Dupont wires have enough length to swivel and make contact

with the OLED pins, I made a mistake on my first try and made the wires long enough to

“reach” but too short to actually connect with the display.

## Switch Wiring

Gather the following:

- 7 Regular Wires
- Electrical tape

Wiring description:

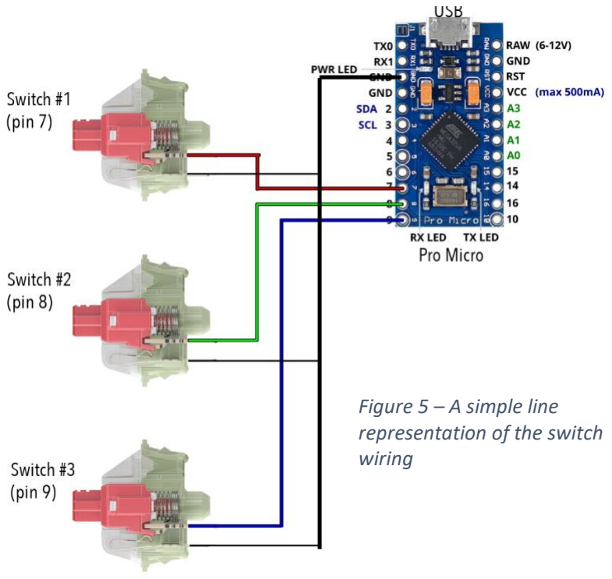
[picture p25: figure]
Figure 5 – A simple line representation of the switch wiring

- One pin on each switch → GND on Pro Micro
- Other pin on Switch #1 → Pin 7 on Pro Micro
- Other pin on Switch #2 → Pin 8 on Pro Micro
- Other pin on Switch #3 → Pin 9 on Pro Micro

Procedure

NOTE: For simplicity’s sake, its probably easier to solder wires to the actual switches themselves during the final assembly process. In the Final Assembly Build Guide, this procedure will be referenced.

To wire up the switches, the most important thing to keep an eye on is wire length. You’ll want to carefully measure out wire lengths that more or less directly reach each switch.

The wiring looks more complex than it is – basically, one pin of each switch needs to connect to ground, and the other pin connects to a pin on the Pro Micro.

For the ground wires, I cheated a little bit and soldered one wire to a pin on the Pro Micro, which then spliced into three “branches”, one for each switch. I used some electrical tape to insulate the joint where I spliced wires.

Make sure you check which pin is connected to which switch. If you’re using the stock firmware, (looking from the top), the bottom switch (play/pause) will be switch #1, the leftmost switch (rewind) will be switch #2, and the rightmost switch (fast-forward) will be switch #3. If you mess this up, you can reassign the switch pins in the firmware before you flash it.

## Full Wiring Diagram

A full, PDF version of this diagram is available at the GitHub repostitory:

https://github.com/adamlechowicz/Beton3/tree/master/Wiring%20Diagram

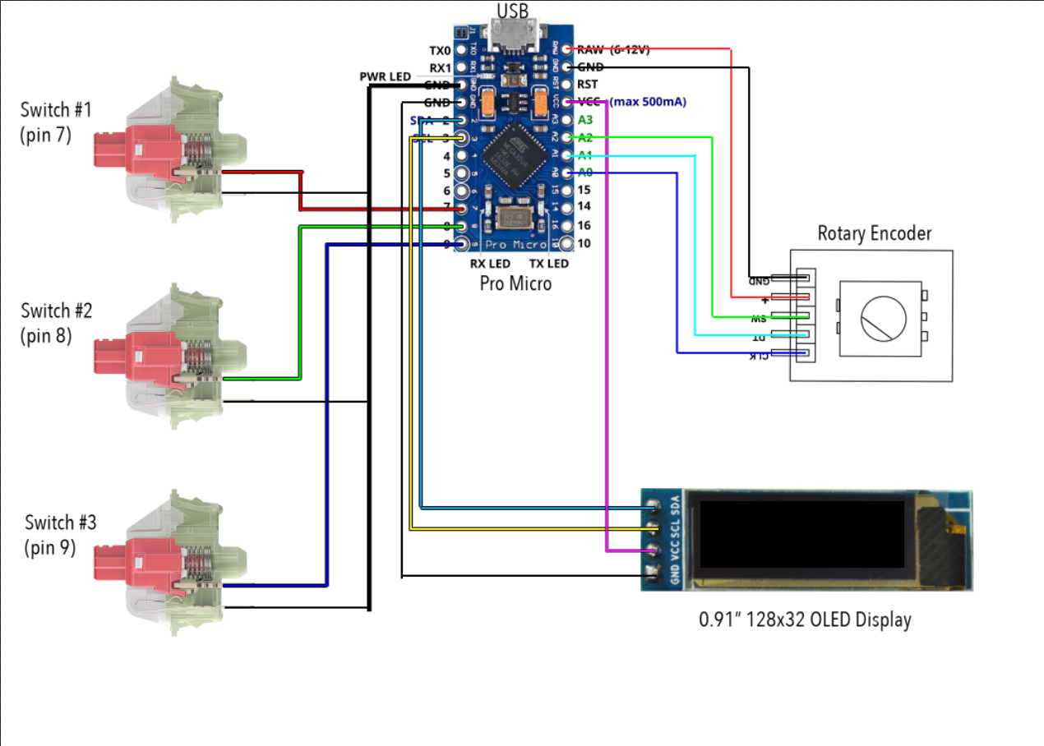
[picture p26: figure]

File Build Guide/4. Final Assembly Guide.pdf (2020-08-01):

# Béton3 // Build Guide

# Final Assembly Guide

Welcome to the final Build Guide for Béton3. This Build Guide outlines a basic overview of

the final assembly you’ll need to do to finish building Béton3.


## Table of Contents

- Pg. 2 – Overview, required parts
- Pg. 3 – Attaching the Top Bezel to the Main Chassis
- Pg. 4 – Installing the Pro Micro and Rotary Encoder
- Pg. 5 – Installing the OLED Display and Connecting It
- Pg. 6 – Installing Switches, Wiring Them
- Pg. 7 – Installing the Rotary Encoder Knob
- Pg. 8 – Bottom Cover, Neoprene Foam Application

## Overview

Before starting with final assembly, you will need the following parts and materials in front of

you.

1. Top Bezel
2. Main Chassis
3. Bottom Cover
4. Screen Bezel (see Appendix A: Making a Screen Bezel from Polycarbonate)
5. Adhesive Neoprene Foam
6. Concrete Knob (see Appendix B: Casting a Concrete Knob)
7. Pro Micro, with wires soldered directly to it, according to the Soldering Guide (https://github.com/adamlechowicz/Beton3/blob/master/Build%20Guide/3.%20Soldering%20Guide.pdf)
- NOTE: before installing the Pro Micro, it’s critical to have the wires soldered to

it labeled, because once it is installed in the chassis, it’s near impossible to

visually see which wire connects to which pin.

8. Rotary Encoder
9. #2 Wood Screws – ¼” long (you’ll need at least 4)
10. 3 MX-compatible Switches
11. OLED Display
12. Hot Glue Gun with Hot Glue
13. Soldering Iron
14. Screwdriver
15. A USB cable compatible with your Pro Micro

## Attaching the Top Bezel to the Main Chassis

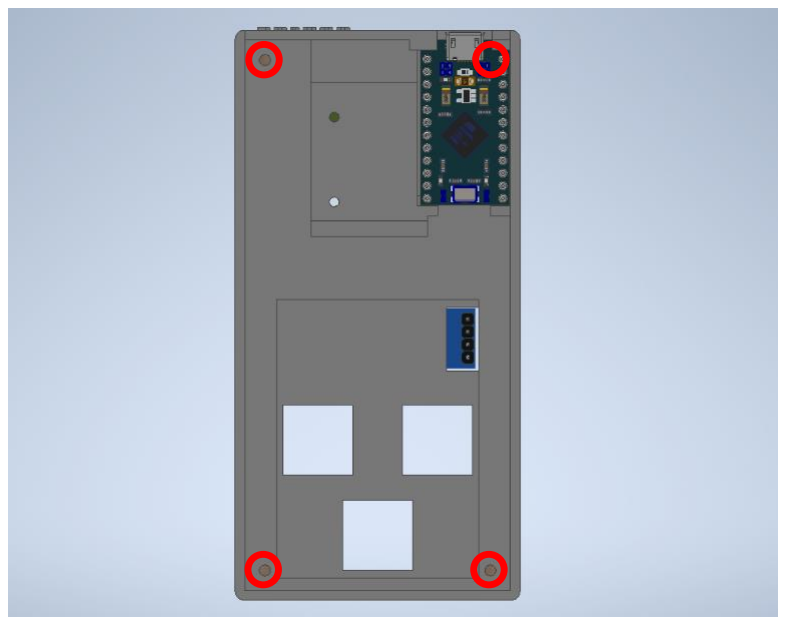
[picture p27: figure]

The Béton3 top bezel is connected to

the main chassis with 4 wood screws,

one in each corner. You’ll notice that

the screw hole at the top left (looking

from the bottom, as in Figure 1) is

underneath the Pro Micro’s mounting

position, hence why this step must be

completed first.

The top bezel is reversible, so choose

the side that you want facing outwards

and align the bezel with the chassis.

Make sure you peel off any protective layers from the laser-cutting process before screwing

into the bezel.

With the chassis on top of the bezel, face down, firmly hold the two pieces together, making

sure the edges are perfectly flush on all four sides, and use the ¼ inch #2 wood screws to

slowly, gently screw the two parts together. Try to screw in just far enough that the screw is

snug, but not too much that you damage the wood underneath. It’s probably worth screwing

in all four screws a little bit to get the positioning right, then tightening all four in a star

pattern (from corner to opposite corner, like a wheel on a car).

When finished, the two parts should fit together snug, with little to no visible gap.

Figure 1 – The screw holes in question.

## Installing the Pro Micro and Rotary Encoder

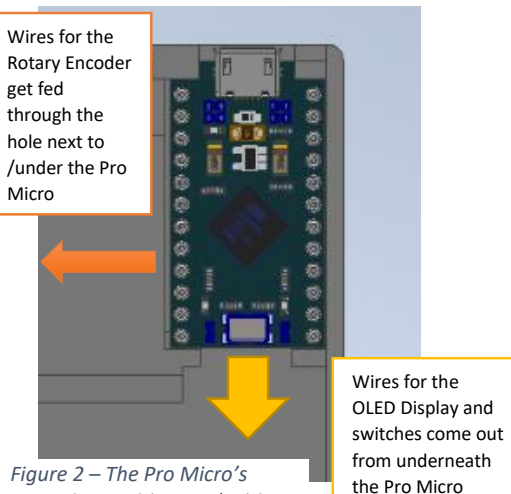
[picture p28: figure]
Figure 2 – The Pro Micro’s; Wires for the Rotary Encoder get fed through the hole next to /under the Pro Micro; Wires for the OLED Display and switches come out from underneath

Before doing anything else, make absolutely sure that you understand which wires will be connecting to which components (I made this mistake while assembling my own design). Whether that’s labeling wires, writing down color codes, or whatever works for you, it’s important as the wires will soon be tucked underneath the Pro Micro and solder joints/pins will be hidden.

Positioning the Pro Micro

As described in Figure 2, in this next step you’ll position and manage the wiring to feed away from the Pro Micro in two primary directions: left and down. Wires connecting to the
Rotary Encoder will feed through the adjacent hole
outwards to the left, and wires for everything else get
tucked underneath the Pro Micro and feed through a gap in the chassis downwards.

Rotary Encoder

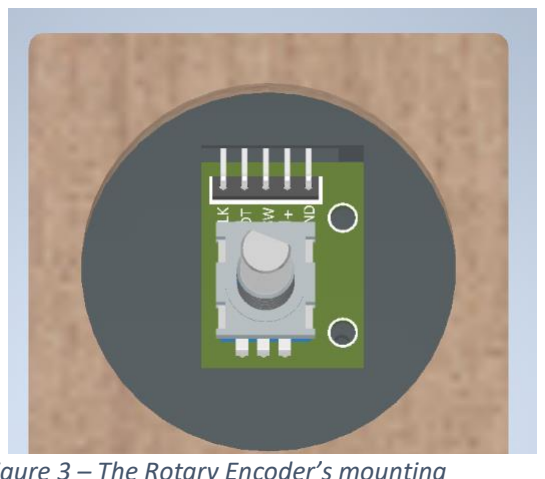
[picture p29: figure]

Once the Pro Micro is in position, connect the Dupont wires to the pre-soldered pins on the Rotary Encoder. The excess wiring for the encoder will now tuck into the back of the chassis and down underneath the Pro Micro.

This step is tricky, as the chassis is purposely designed to be a tight fit for the Rotary Encoder. Once the encoder is wired up, you have to essentially try to pivot it down into the cradle, pushing upwards and down to press fit. If you’re having a lot of trouble with this step, you may have to trim the Dupont connectors some more (see Soldering Guide), or shorten the wires from the Pro Micro. Once you get it, it should fit snugly against the case, with little movement, and the encoder shaft should be pointing at a 90 degree angle from the case.

Hot Glue

Once both are successfully installed, you’ll want to use some hot glue to semi-permanently affix both parts to the chassis. I had success using dabs of hot glue in corners, underneath parts, and between flat sections to keep parts from moving.

mounting position, and wiring exit directions.

the Pro Micro
through the gap

Figure 3 – The Rotary Encoder’s mounting position

## Installing the OLED Display and Connecting it

Now that you’ve attached the top bezel,

mounting the OLED to the chassis is fairly

straightforward. The display mounts directly to

the chassis through a rectangular cutout in the

wooden top bezel roughly the same size as the

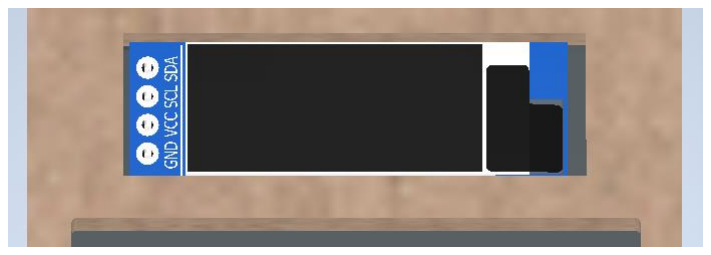
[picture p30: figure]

display’s PCB. The pins of the display poke through the chassis hole mentioned in the

Soldering Guide. When I did this assembly, I used some double-sided 3M mounting tape

(the foam-type, thick stuff, with red peel-off film), but hot glue should also work perfectly.

Positioning

One of the simpler steps of this build, you’ll basically just want to center the display in the

cutout as best as you can and use your mounting method of choice to affix it directly to the

plastic.

Black Screen Bezel

If you have a bezel for the screen (see Appendix A: Making a Screen Bezel from

Polycarbonate), mounting it is super simple. Use two dabs of hot glue on either side of the

PCB, left and right, and position the bezel within the rectangular cutout of the wooden top

bezel. Make sure you get rid of any dust on the screen or bezel before mounting.

Wiring

If you’ve labeled all your wires, this part should be fairly simple. You’ll want to carefully bend

the pins of the OLED display inwards (towards the left when looking at the bottom of the

chassis) and use the Dupont wires soldered to the Pro Micro to connect the display.

Figure 1 – The OLED Display’s mounting position

## Installing Switches, Wiring Them

Now for the fun part – installing the switches! This

part is also fairly simple: each switch snaps into it’s

designated mounting hole in the chassis. If desired,

and depending on the tolerances of the 3d printed

chassis, you can also use hot glue to further secure

each switch into the chassis.

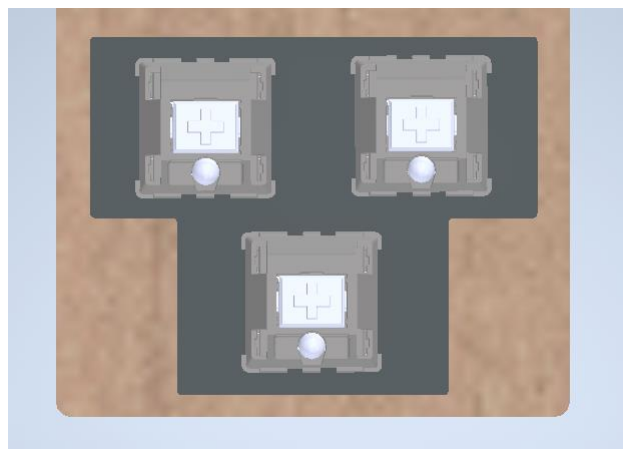
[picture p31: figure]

Wiring

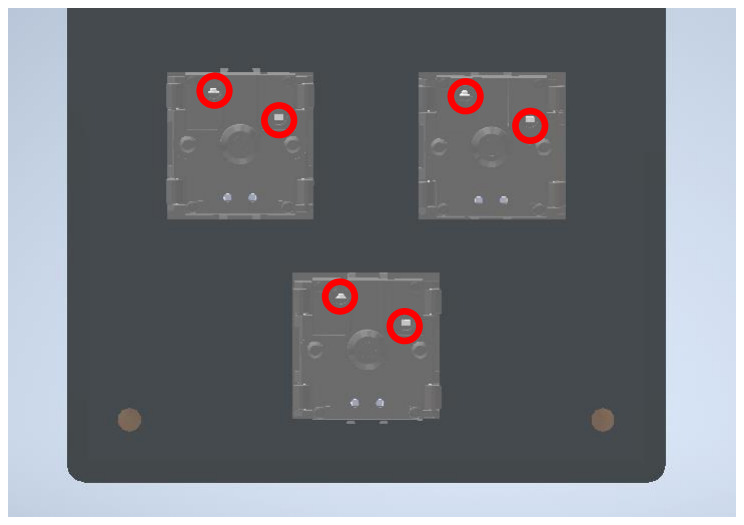
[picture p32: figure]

Each switch has two pins, which get soldered

to either a ground wire, or a wire directly

connected to a pin on the Pro Micro. The

details of this wiring are listed in the

Soldering Guide. (https://github.com/adamlechowicz/Beton3/blob/master/Build%20Guide/3.%20Soldering%20Guide.pdf) Since you should already

have loose wires intended to connect to

each switch, this step is just a matter of

wrapping each respective wire around a pin

on a switch and using a soldering iron to

connect them.

NOTE: I found that Switch #1 (the closest to the front edge of the unit), should have its pins

bent slightly towards the back of the unit, just to avoid any clearance issues with the sliding

bottom cover.

Figure 2 – The switch mounting positions

Figure 6 – Looking at the bottom of the chassis, the bottom of each switch and their respective pins (highlighted).

## Installing the Concrete Rotary Encoder Knob

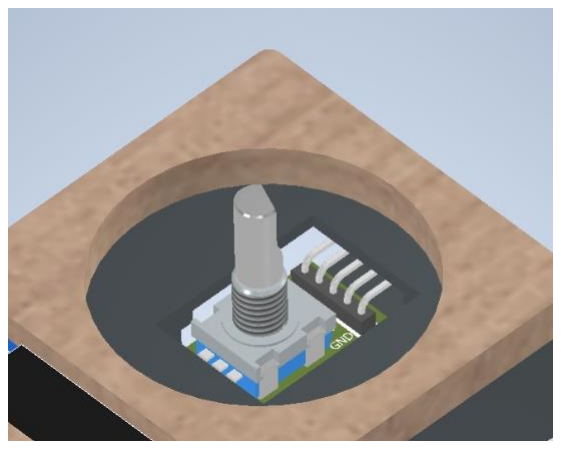
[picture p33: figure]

For the final major step, you’ll need to install the

Concrete Knob onto the Rotary Encoder. This step is

also fairly simple, but don’t be afraid to do some trial-

and-error to get it perfectly centered.

Procedure

What you’re basically doing in this step is attaching the

innermost hole to the rotating shaft of the Rotary

Encoder. When the concrete knob comes out of the

mold (see Appendix B: Casting a Concrete Knob if you

need to cast one), it has a hole on the bottom that

looks something like Figure 8 to the left.

What you want to do is essentially put one or two

pumps of hot glue into the innermost hole, marked by

the blue dot, and then quickly press the knob onto the

rotary encoder shaft before the glue cools.

I’ve found that the best way to do this is to prop up the

whole chassis with something small like a bottle cap

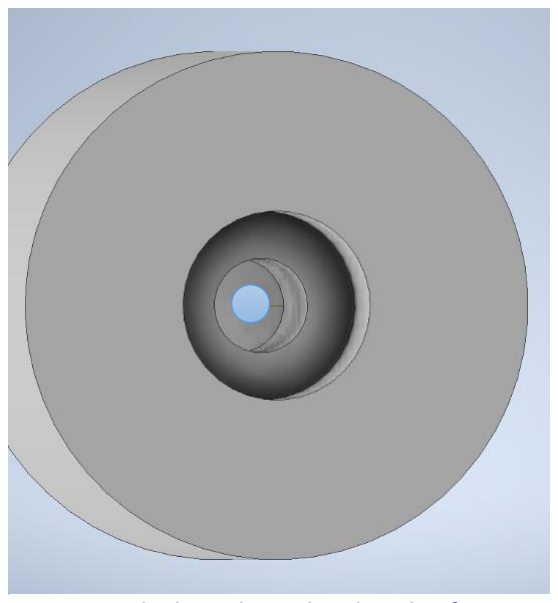
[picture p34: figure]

first, to get rid of the slight angle in the case and make the top mostly level. Then, put some

hot glue into the knob, center it above the circular cutout in the wooden bezel, and slowly

press down onto the shaft of the rotary encoder, making sure to apply uniform pressure on

all sides of the knob (eg: use the tips of your fingers on the side of the knob, don’t press

down on the knob with your palm)

Hold the knob there for about 30 seconds while the hot glue hardens. When it does, you

should be able to let go and spin the knob freely, without any scraping.

If the knob does scrape against the wooden bezel, you can gently peel it off of the shaft by

rocking it back and forth while applying even pressure upwards. This is definitely a trial-and-

error step, so do this as many times as you see fit until you have a result you’re satisfied

with.

Figure 7 – The Rotary Encoder’s shaft

Figure 8 – The hypothetical underside of a concrete knob

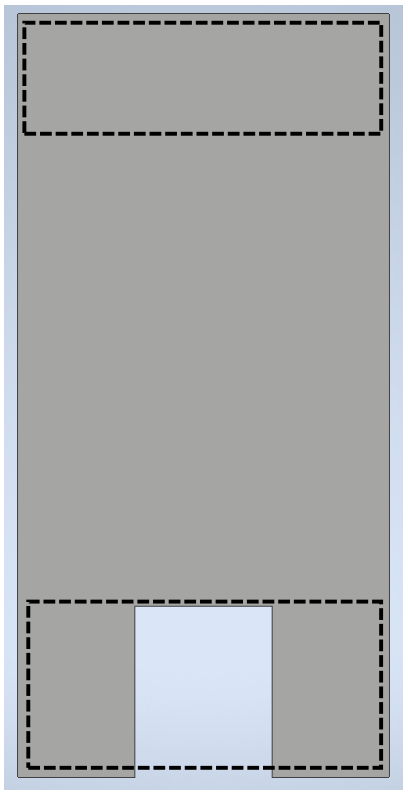
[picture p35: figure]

## Installing the Bottom Sliding Cover

Molded into the main chassis, there are two

“rails” along the left and right walls that

accept a sliding bottom cover to finish off

this build. Before sliding on this cover, one

last step you may want to do involves

sticking on some neoprene foam to prevent

the whole unit from sliding around on your

desk.

Cut two strips of neoprene, roughly according

to the dotted rectangles in Figure 8.

The strip of neoprene furthest away from the

back “lip” should be large enough to cover

the slight cutout in the sliding cover (as

mentioned before, this cutout allows the

whole unit to be thinner and provides

clearance for the switch pins underneath it)

Once completed, simply slide the bottom

cover into the main chassis, making sure the

rear lip of the bottom cover matches up with

the rear wall of the chassis.

Congratulations! You have assembled Béton3.

If you will be using the stock firmware, proceed to Appendix C: Flashing Stock Firmware to

install it.

Figure 8 – The underside of the bottom sliding cover, with rectangles representing where foam should be stuck on.

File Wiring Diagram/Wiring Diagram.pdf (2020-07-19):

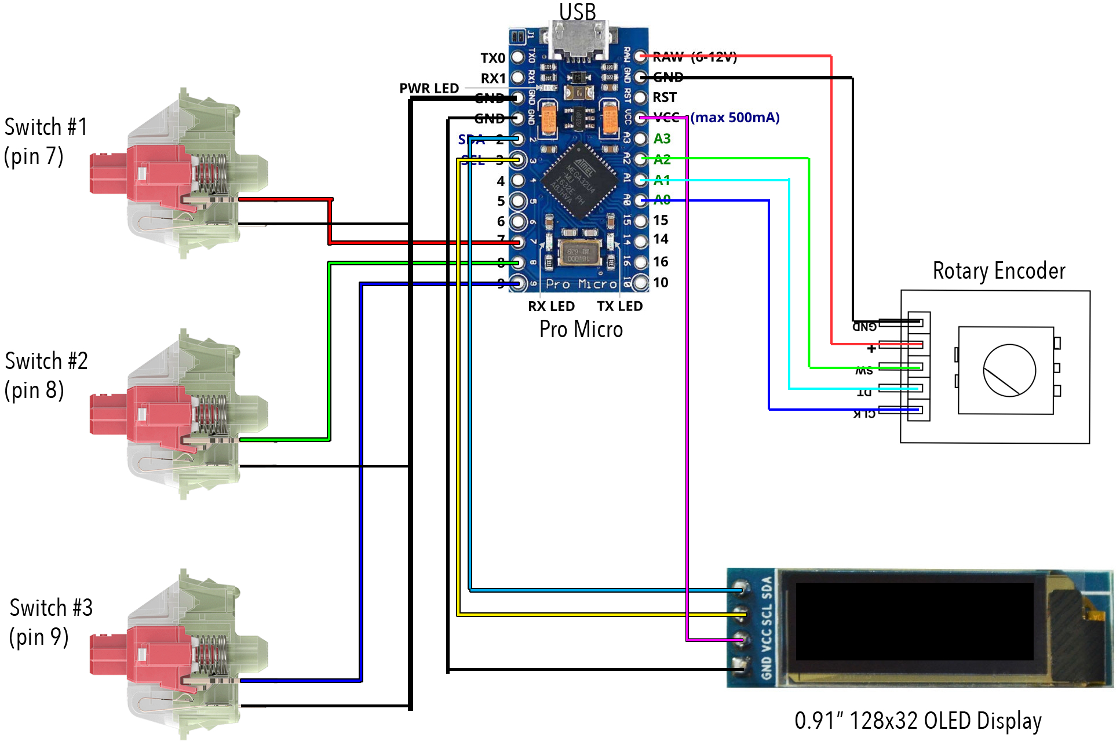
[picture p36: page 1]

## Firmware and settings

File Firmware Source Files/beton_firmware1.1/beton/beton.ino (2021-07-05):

//Required External Arduino Libraries
#include <ClickEncoder.h>
#include <TimerOne.h>
#include <HID-Project.h>

//Header Files included with Beton Firmware
#include "oled.h"
//oled.h includes important setup for the OLED display
#include "acknowledge.h"
#include "play.h"
#include "forwardback.h"
#include "nextprev.h"
#include "volupdown.h"
#include "version.h"

template<typename T>
struct TimeStampedValue {
  explicit TimeStampedValue(T value) : _value(value), _timeStamp(0) {}
  void set(const T& value) { _value = value; touch(); }
  operator const T&() const { return _value; }
  void touch() { _timeStamp = millis(); }
  unsigned long getTimeStamp() const { return _timeStamp; }
  
private:
  T _value;
  unsigned long _timeStamp;
};


//these #define statements dictate which pin connects to which button.
//Eg: Button1 is pin 7, etc.
#define BUTTON1    9
#define BUTTON2    8
#define BUTTON3    7

//these integers are counters which monitor how long each button has been clicked
//for, enabling long-press functions such as rewind.
int button1Clicked = 0;
int button2Clicked = 0;
int button3Clicked = 0;
int encoderClicked = 0;

int encoderValue = 0;

//this statement initializes the encoder on pins A1, A0 and A2
ClickEncoder encoder(A1, A0, A2);

TimeStampedValue<int16_t> value(0);
int16_t current = 0;

void timerIsr() {
  encoder.service();
}

void setup() {
  //starts serial communication over USB
  Serial.begin(9600);

  //enables internal pullup resistors for each button pin
  pinMode(BUTTON1, INPUT_PULLUP);
  pinMode(BUTTON2, INPUT_PULLUP);
  pinMode(BUTTON3, INPUT_PULLUP);

  //starts timer that interrupts when encoder is clicked
  Timer1.initialize(1000);
  Timer1.attachInterrupt(timerIsr);

  //initializes libraries that support USB HID (Consumer) and
  //OLED display (u8g2)
  Consumer.begin();
  u8g2.begin();

  //tick runs at the rate of 30FPS, the refresh rate for the display
  tick.start(FPS, AsyncDelay::MILLIS);

  //displays the startup splash screen
  animation = SPLASH;
}

//Main loop
void loop() {
  //checks to see if the rotary encoder has turned
  current += encoder.getValue();
  auto diff = current - value;
  
  if (diff != 0) {

    encoderValue += diff;
    Serial.println(encoderValue);

    //if turned counter-clockwise, display animation 
    if (diff < 0){
      animation_state = 0;
      animation = DOWN;
    }
    //if turned clockwise, display animation 
    else if (diff > 0){
      animation_state = 0;
      animation = UP;
    }
    //if turned clockwise enough, volume up 
    if (encoderValue > 3) {
      Consumer.write(MEDIA_VOL_UP);
      encoderValue = 0;
      delay(60);      
    } 
    //if turned counter-clockwise enough, volume down
    else if (encoderValue < -3) {
      Consumer.write(MEDIA_VOL_DOWN);
      encoderValue = 0;
      delay(60);              
    }
    value.set(current);
  }

  //check to see if the rotary encoder has been clicked
  ClickEncoder::Button b = encoder.getButton();
  if (b != ClickEncoder::Open) {
    encoderClicked++;
    switch (b) {
      case ClickEncoder::Clicked:
        //if we are displaying splash screens, get rid of them
        if (animation == ACKNOWLEDGE || animation == VERSION){
          acknowledgeReset();
          animation = NONE;
          break;
        }
        //if the encoder is not being long pressed, mute the volume and animate
        if(encoderClicked < 3){
          Consumer.write(MEDIA_VOL_MUTE);
          animation_state = 0;
          animation = MUTE;
        }            
        break;
    }
    //if the encoder has been held down for 100 cycles, display the "credits" animation
    if (encoderClicked > 100){
        animation_state = 0;
        animation = ACKNOWLEDGE;
    }
  } else {
    encoderClicked = 0;
  }

  //Play-Pause Button Logic
  int button1Value = digitalRead(BUTTON1);
  if (button1Value == LOW){
     button1Clicked++;
     delay(100);
     button1Value = digitalRead(BUTTON1);

     //if the button is clicked and is not being long pressed, play/pause and animate
     if (button1Value != LOW && button1Clicked < 30){
        animation_state = 0;
        animation = PLAY;
        Consumer.write(MEDIA_PLAY_PAUSE);
     } 
     
     //if the button is being long pressed, display the version number for the firmware.
     if (button1Clicked > 30){
        animation_state = 0;
        animation = VERSION;
        delay(250);
      }
  } else {
    button1Clicked = 0;
  }

  //Previous & Rewind Button Logic
  int button2Value = digitalRead(BUTTON2);
  if (button2Value == LOW){
     button2Clicked++;
     delay(100);
     button2Value = digitalRead(BUTTON2);

     //if the button is clicked and is not being long pressed, previous and animate
     if (button2Value != LOW && button2Clicked < 3){
        animation_state = 0;
        animation = PREV;
        Consumer.write(MEDIA_PREV);
     } 
     //if the button is being long pressed, display the rewind animation and repeatedly send rewind keystrokes.
     if (button2Clicked > 3){
        animation_state = 0;
        animation = REWIND;
        Consumer.write(MEDIA_REWIND);
        delay(250);
      }
  } else {
    button2Clicked = 0;
  }

  //Next & Fast-Forward Button Logic
  int button3Value = digitalRead(BUTTON3);
  if (button3Value == LOW){
     button3Clicked++;
     delay(100);
     button3Value = digitalRead(BUTTON3);

     //if the button is clicked and is not being long pressed, next and animate
     if (button3Value != LOW && button3Clicked < 3){
        animation_state = 0;
        animation = NEXT;
        Consumer.write(MEDIA_NEXT);
     } 
     //if the button is being long pressed, display the rewind animation and repeatedly send fast forward keystrokes.
     if (button3Clicked > 3){
        animation_state = 0;
        animation = FORWARD;
        Consumer.write(MEDIA_FAST_FORWARD);
        delay(250);
      }
  } else {
    button3Clicked = 0;
  }

  //30 times a second (30 FPS), the tick "expires" and displays an animation (or none):
  if (tick.isExpired()) {
    switch(animation){
      
      //if theres no animation active, just clear the display
      case NONE:
        u8g2.clearDisplay();
        break;
        
      //if there is an animation active, draw it, increment the animation state,
      //repeat the tick.
      
      case ACKNOWLEDGE:
        drawAcknowledge();
        animation_state++;
        tick.repeat();
        break;
        
      case PLAY:
        drawPlay();
        animation_state++;
        tick.repeat();
        break;
        
      case NEXT:
        drawNext();
        animation_state++;
        tick.repeat();
        break;
        
      case PREV:
        drawPrev();
        animation_state++;
        tick.repeat();
        break;
        
      case FORWARD:
        drawForward();
        animation_state++;
        tick.repeat();
        break;
        
      case REWIND:
        drawRewind();
        animation_state++;
        tick.repeat();
        break;
        
      case UP:
        drawPlus();
        animation_state++;
        tick.repeat();
        break;
        
      case DOWN:
        drawMinus();
        animation_state++;
        tick.repeat();
        break;
        
      case MUTE:
        drawMute();
        animation_state++;
        tick.repeat();
        break;
        
      case VERSION:
        drawVersion();
        animation_state++;
        tick.repeat();
        break;
        
      case SPLASH:
        drawSplash();
        animation_state++;
        tick.repeat();
        break;
    }
  }
}

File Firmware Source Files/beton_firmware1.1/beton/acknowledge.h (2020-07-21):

//A bunch of definitions for the width of each graphical element
#define mountain_width 128
#define mountain_height 16
#define text_width 128
#define text_height 16
#define splash_width 88
#define splash_height 18

//XBM format, first section of text
static const unsigned char text1[] U8X8_PROGMEM = {
 0x00,0x00,0x00,0x00,0x00,0x00,0x00,0x00,0x00,0x00,0x00,0x00,0x00,0x00,0x00,
 0x00,0x00,0x00,0x00,0x00,0x00,0x00,0x00,0x00,0x00,0x00,0x00,0x00,0x00,0x00,
 0x00,0x00,0x00,0x00,0x00,0x00,0x00,0x00,0x00,0x00,0x00,0x00,0x00,0x00,0x00,
 0x00,0x00,0x00,0x00,0x10,0x00,0x00,0x00,0x00,0x00,0x00,0x00,0x00,0x00,0x00,
 0x00,0x00,0x00,0x00,0x1f,0x08,0x06,0x00,0xc0,0x0f,0x00,0x02,0x00,0x40,0x00,
 0x01,0x00,0x00,0x02,0x00,0x33,0x00,0x06,0x00,0x00,0x06,0x00,0x02,0x00,0x40,
 0x00,0x01,0x00,0x00,0x02,0x00,0x33,0x1e,0x8f,0xc7,0x07,0x03,0x00,0x1e,0x11,
 0xa0,0xe0,0x71,0x34,0x03,0x02,0x0e,0x33,0x33,0xc6,0xcc,0x8c,0x07,0x00,0x22,
 0x11,0xa0,0x10,0x89,0xcc,0x04,0x02,0x91,0x1f,0x33,0xc6,0xcc,0x0c,0x0c,0x1f,
 0x22,0x11,0x10,0x11,0xf1,0x44,0x04,0x02,0x91,0x33,0x3f,0xc6,0xcc,0x0c,0x0c,
 0x00,0x22,0x11,0x10,0x11,0x89,0x44,0x04,0x02,0x9f,0x33,0x03,0xc6,0xcc,0x0c,
 0x0c,0x00,0x22,0x11,0xf8,0x13,0x89,0x44,0x04,0x02,0x81,0x33,0x23,0xc6,0xcc,
 0x4c,0x0c,0x00,0x22,0x11,0x08,0x12,0x89,0x44,0x04,0x02,0x91,0x1f,0x1e,0x8c,
 0xc7,0x8c,0x07,0x00,0x1e,0x1e,0x08,0xe2,0xf1,0x44,0x04,0x3e,0x0e,0x00,0x00,
 0x00,0x00,0x00,0x00,0x00,0x00,0x10,0x00,0x00,0x00,0x00,0x00,0x00,0x00,0x00,
 0x00,0x00,0x00,0x00,0x00,0x00,0x00,0x11,0x00,0x00,0x00,0x00,0x00,0x00,0x00,
 0x00,0x00,0x00,0x00,0x00,0x00,0x00,0x00,0x0e,0x00,0x00,0x00,0x00,0x00,0x00,
 0x00 };

//XBM format, second section of text
static const unsigned char text2[] U8X8_PROGMEM = {
 0x00,0x00,0x00,0x00,0x00,0x00,0x00,0x00,0x00,0x00,0x00,0x00,0x00,0x00,0x00,
 0x00,0x00,0x00,0x00,0x00,0x00,0x00,0x00,0x00,0x00,0x00,0x00,0x00,0x00,0x00,
 0x00,0x00,0x00,0x00,0x00,0x00,0x00,0x00,0x00,0x00,0x00,0x00,0x00,0x00,0x00,
 0x00,0x00,0x00,0x00,0x00,0x00,0x00,0x00,0x00,0x00,0x00,0x00,0x00,0x00,0x00,
 0x00,0x00,0x00,0x00,0x40,0x00,0x00,0x00,0x01,0x00,0x00,0x20,0x08,0x00,0x02,
 0x00,0x01,0x80,0x80,0x00,0x40,0x00,0x00,0x00,0x00,0x00,0x00,0x60,0x0c,0x00,
 0x02,0x00,0x00,0x80,0x80,0x00,0x47,0xc3,0x11,0x91,0xe1,0xf8,0x00,0xa0,0x8a,
 0xc3,0xe3,0x80,0xd1,0x80,0x88,0x38,0xc8,0x24,0x12,0x11,0x11,0x81,0x00,0x20,
 0x49,0x24,0x12,0x01,0x31,0x01,0x49,0x44,0x40,0x24,0xa2,0x0a,0x11,0x40,0xf0,
 0x21,0x88,0x27,0x12,0x01,0x11,0x01,0x55,0x44,0x40,0x24,0xa2,0x0a,0x11,0x20,
 0x00,0x20,0x48,0x24,0xf2,0x01,0x11,0x01,0x55,0x7c,0x40,0x24,0x42,0x04,0x11,
 0x10,0x00,0x20,0x48,0x24,0x12,0x00,0x11,0x01,0x22,0x04,0x48,0x24,0x42,0x04,
 0x11,0x09,0x00,0x20,0x48,0x24,0x12,0x01,0x11,0x01,0x22,0x44,0x47,0xc4,0x41,
 0x04,0xe1,0xf8,0x00,0x20,0x88,0xc7,0xe3,0x00,0x11,0x01,0x22,0x38,0x00,0x00,
 0x00,0x00,0x00,0x00,0x00,0x00,0x00,0x00,0x00,0x00,0x00,0x00,0x00,0x00,0x00,
 0x00,0x00,0x00,0x00,0x00,0x00,0x00,0x00,0x00,0x00,0x00,0x00,0x00,0x00,0x00,
 0x00,0x00,0x00,0x00,0x00,0x00,0x00,0x00,0x00,0x00,0x00,0x00,0x00,0x00,0x00,
 0x00 };

//XBM format, third section of text
static const unsigned char text3[] U8X8_PROGMEM = {
 0x00,0x00,0x00,0x00,0x00,0x00,0x00,0x00,0x00,0x00,0x00,0x00,0x00,0x00,0x00,
 0x00,0x00,0x00,0x00,0x00,0x00,0x00,0x00,0x00,0x00,0x00,0x00,0x00,0x00,0x00,
 0x00,0x00,0x00,0x00,0x00,0x00,0x00,0x00,0x00,0x00,0x00,0x00,0x00,0x00,0x00,
 0x00,0x00,0x00,0x00,0x00,0x00,0x00,0x00,0x00,0x00,0x00,0x00,0x00,0x00,0x00,
 0x00,0x00,0x00,0x00,0x00,0x02,0x00,0x00,0x40,0x10,0x00,0x00,0x00,0x00,0x04,
 0x00,0x00,0x80,0x20,0x00,0x00,0x02,0x00,0x00,0xc0,0x18,0x00,0x00,0x00,0x00,
 0x04,0x00,0x00,0x80,0x20,0x00,0x1c,0x87,0xa3,0x6b,0x40,0x15,0x87,0xc3,0xe1,
 0x70,0x34,0x22,0x0e,0xc7,0x71,0x38,0x22,0x42,0x64,0x98,0x40,0x92,0x48,0x24,
 0x12,0x89,0x4c,0x22,0x91,0x88,0x20,0x44,0x02,0x42,0x24,0x88,0x40,0x10,0x4f,
 0x20,0xe0,0x09,0x44,0x22,0x81,0x88,0x20,0x04,0x1c,0xc2,0x27,0x88,0x40,0x90,
 0x88,0xc3,0x11,0x09,0x44,0x22,0x8e,0x8f,0x20,0x38,0x20,0x42,0x20,0x88,0x40,
 0x90,0x08,0x04,0x12,0x09,0x44,0x22,0x90,0x80,0x20,0x40,0x22,0x42,0x24,0x88,
 0x40,0x90,0x48,0x24,0x12,0x89,0x44,0x32,0x91,0x88,0x20,0x44,0x1c,0x8c,0x23,
 0x88,0x40,0x10,0x8f,0xc3,0xe1,0x71,0x44,0x2c,0x0e,0x07,0xc3,0x38,0x00,0x00,
 0x00,0x00,0x00,0x00,0x00,0x00,0x00,0x00,0x00,0x00,0x00,0x00,0x00,0x00,0x00,
 0x00,0x00,0x00,0x00,0x00,0x00,0x00,0x00,0x00,0x00,0x00,0x00,0x00,0x00,0x00,
 0x00,0x00,0x00,0x00,0x00,0x00,0x00,0x00,0x00,0x00,0x00,0x00,0x00,0x00,0x00,
 0x00 };

//XBM format, a crappy outline of the Holyoke Range in Western Massachusetts
static const unsigned char mountains[] U8X8_PROGMEM = {
 0x00,0x00,0x00,0x00,0x00,0x00,0x00,0x00,0x00,0x00,0x00,0x00,0x00,0x00,0x00,
 0x00,0x00,0x00,0x00,0x00,0x00,0x00,0x00,0x00,0x00,0x00,0x00,0x00,0x00,0x38,
 0x00,0x00,0x00,0xf8,0x03,0x00,0x00,0x00,0x00,0x00,0x00,0x00,0x00,0x00,0x80,
 0xc7,0x03,0x00,0x00,0x04,0x3c,0x00,0x00,0x00,0x00,0x00,0x00,0xf0,0x00,0x00,
 0x60,0x00,0x1c,0x00,0x00,0x03,0xc0,0x03,0x00,0x00,0x00,0x00,0x00,0x08,0x03,
 0x00,0x1e,0x00,0xe0,0x03,0xf0,0x00,0x00,0x7c,0x00,0x00,0x00,0x00,0x00,0x06,
 0x0c,0xe0,0x01,0x00,0x00,0x3c,0x0f,0x00,0x00,0x80,0x07,0x00,0x00,0xe0,0x83,
 0x01,0x30,0x1c,0x00,0x00,0x00,0xc0,0x00,0x00,0x00,0x00,0xf8,0x00,0x00,0x1e,
 0x7c,0x00,0xc0,0x03,0x00,0x00,0x00,0x00,0x00,0x00,0x00,0x00,0x00,0x0f,0xc0,
 0x01,0x10,0x00,0x30,0x00,0x00,0x00,0x00,0x00,0x00,0x00,0x00,0x00,0x00,0xf0,
 0x38,0x00,0x20,0x00,0x0c,0x00,0x00,0x00,0x00,0x00,0x00,0x00,0x00,0x00,0x00,
 0x00,0x07,0x00,0xc0,0x80,0x03,0x00,0x00,0x00,0x00,0x00,0x00,0x00,0x00,0x00,
 0x00,0xc0,0x01,0x00,0x00,0x61,0x00,0x00,0x00,0x00,0x00,0x00,0x00,0x00,0x00,
 0x00,0x00,0x3c,0x00,0x00,0x00,0x1e,0x00,0x00,0x00,0x00,0x00,0x00,0x00,0x00,
 0x00,0x00,0x80,0x03,0x00,0x00,0x00,0x03,0x00,0x00,0x00,0x00,0x00,0x00,0x00,
 0x00,0x00,0x00,0x70,0x00,0x00,0x00,0xc0,0x00,0x00,0x00,0x00,0x00,0x00,0x00,
 0x00,0x00,0x00,0x00,0x0f,0x00,0x00,0x00,0x30,0x00,0x00,0x00,0x00,0x00,0x00,
 0x00 };
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

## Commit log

2020-07-19 Shuffle firmware files around, add wiring diagram
2020-07-19 Mold 3D Files
    [moldbase.ipt, moldbase.stl, moldside.ipt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]
2020-07-19 Upload 3D Files
    [betonbase.ipt, betonbase.stl, betonbottom.ipt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]
2020-07-19 Create Assembly Beton (shrinkwrapped).ipt
    [Assembly Beton (shrinkwrapped).ipt]
2020-07-26 Add Soldering Guide
2021-07-05 Firmware version bump to 1.1 - much improved psuedo-acceleration on the rotary encoder for volume, better fine-grain control.
